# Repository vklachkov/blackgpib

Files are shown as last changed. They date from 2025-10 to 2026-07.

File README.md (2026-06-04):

# BlackGPIB

BlackGPIB is hardware that emulates GPIB disk drives for the GRiD Compass. It is based on the Raspberry Pi RP2040.

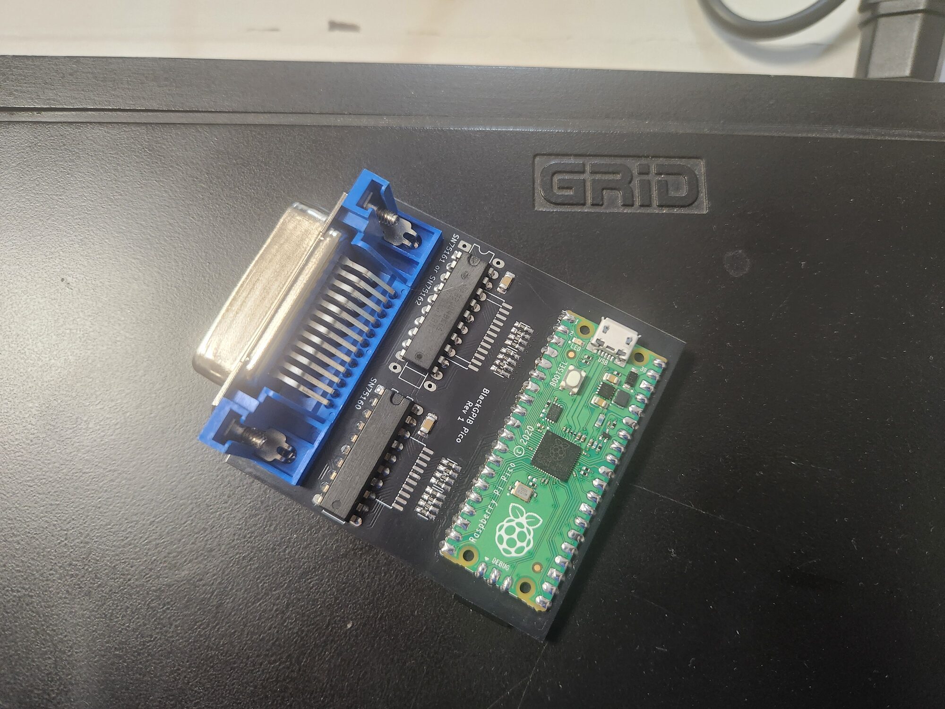
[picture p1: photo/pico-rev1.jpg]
Pico Rev 1


## Hardware

Hardware schematics and design files are located in the `hardware` folder. Production files are available in the [latest release](github.com/vklachkov/blackgpib/releases) on GitHub.

We recommend using the latest `pico` version. The list of components and known issues is described in the `README.md` file located in the `hardware/pico` directory.

## Firmware

The firmware source code is located in the `pico` folder.

The latest stable prebuilt firmware in UF2 format is available in the [latest release](https://github.com/vklachkov/blackgpib/releases) on GitHub.

### Flashing prebuilt firmware

To flash the firmware, hold the **BOOTSEL** button while connecting the Raspberry Pi Pico to your computer. The Pico will appear as a removable drive.

Copy the `blackgpib.uf2` file to this drive. The Pico will reboot automatically after the file is copied.

### Building firmware from source

To build the firmware yourself, install the Pico SDK first. Follow the instructions on the official Raspberry Pi website:

https://www.raspberrypi.com/documentation/microcontrollers/c_sdk.html

Then follow these steps.

1. Clone the repository:

```bash
git clone --depth 1 --recursive https://github.com/vklachkov/blackgpib
```

2. Go to the sources directory:

```bash
cd blackgpib/pico
```

3. Configure the project for your board:

```bash
cmake -S . -B build -DPICO_BOARD=pico
```

4. Build:

```bash
cmake --build build -j
```

5. Flash the firmware:

   Hold the **BOOTSEL** button while connecting the Raspberry Pi Pico to your computer. Then copy the `blackgpib.uf2` file from the `build` folder to the mounted Pico drive.

## How to use it?

After assembling and flashing the device, find a microSD card and format it as FAT32 or exFAT. Copy the disk images to this card. Insert the microSD card into BlackGPIB. Connect BlackGPIB to power, the LED should turn on after about one and a half seconds. After that, you can turn on the GRiD Compass. Enjoy!

### Which file formats are supported?

Currently, only .IMG files are supported. IMD and .CHD are not supported.

If you want to use IMD files from gridrepository.org, please use the [imd2raw](https://github.com/RetroFloppy/imd2raw) converter until BlackGPIB support is not available.

### How is the address selected?

For images that do not have a GPIB address specified in their filename, the address is selected automatically.

Floppy disk images use addresses 5, 6, and 13. Other images use the remaining default addresses (4, 5, 6, 12, 13).

If addresses conflict, or if there are no addresses left, an entry about this will be written to log.txt.

### How do I bind an image to a specific GPIB address?

Rename the image to FXX or HXX, where XX is the GPIB address. For example, FLOPPY4_TEST.IMG or HD12.IMG.

### How do I change the image geometry?

You can’t, it is selected automatically. Geometry configuration is not supported.

### Troubleshooting

**The LED is always off**

Check that you assembled the emulator correctly, powered it, and flashed the correct firmware.

**The device is steadily blinking the LED on the board**

This means that the device does not see the SD card, or the filesystem on it is not FAT.

Remove the SD card, format it again, and insert it into the device. If you did not disconnect power from BlackGPIB, then, if successful, the device will blink the LED several times, and then the LED should stay steadily on. This means that the device is ready to use.

**The device is blinking SOS**

This means that the device has gone into a boot loop. Normally, this should not happen.

Connect the device to your computer, open a serial port monitor, and check what went wrong before the boot loop. You can email me or open an issue, and I will try to help.

## License

This project is released under the [MIT License](LICENSE).

You are free to use, modify, and share it. I will be happy if BlackGPIB helps you bring your GRiD Compass back to life and use it again.

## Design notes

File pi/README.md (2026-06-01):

# BlackGPIB Legacy

This is a project to emulate GPIB peripherals for the [GRiD Compass](https://en.wikipedia.org/wiki/Grid_Compass) computer using Raspberry Pi.

## Features

BlackGPIB can emulate a hard drive and a floppy drive. It also has a printer and plotter proxy. Current version is based on Raspberry Pi 3 or newer. Support for Raspberry Pi 2 is not implemented due to the need to adapt the code for armv6.

For more information about device emulation, see the [Details About Emulation](#details-about-emulation) section.

## Photos

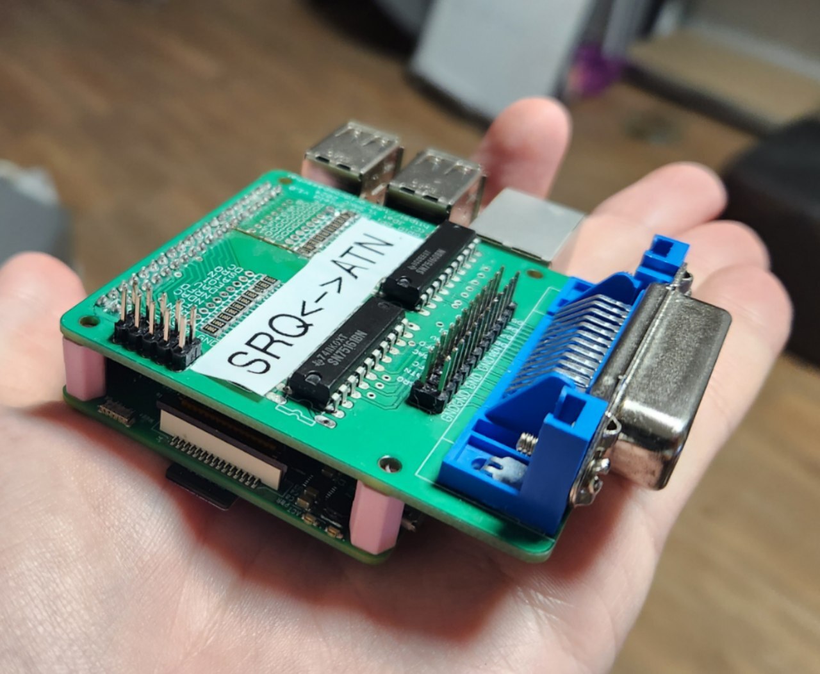
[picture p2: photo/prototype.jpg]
Photo of first prototype

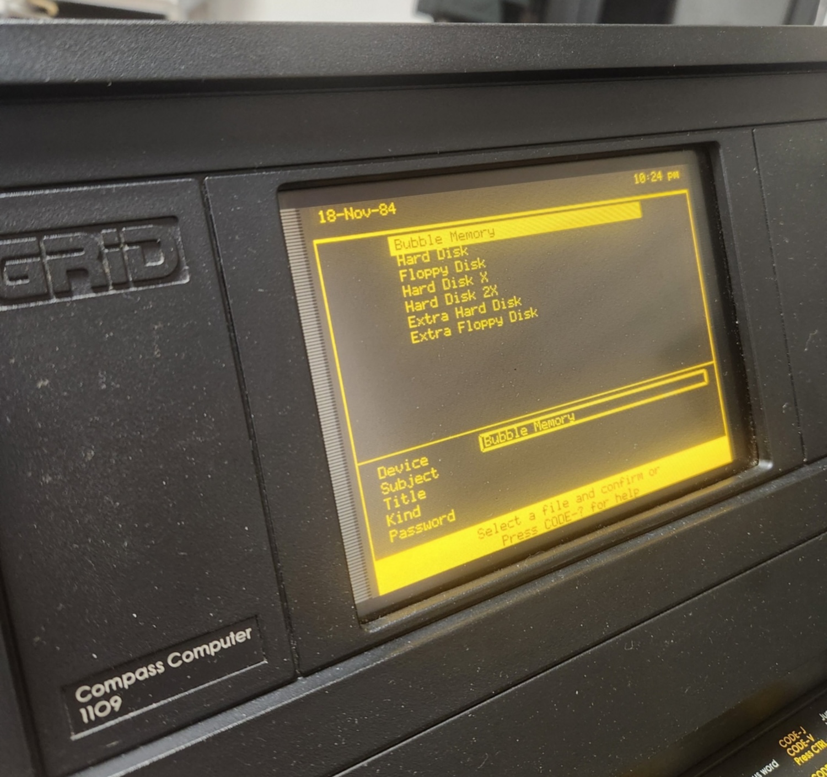
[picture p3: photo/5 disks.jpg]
5 disks


## How to Assemble

There is no illustrated guide, and there won't be one until a new version of the board is developed. If you are interested in assembling a prototype, you can find the board project files and their description in the [`hardware/pi-hat`](/hardware/pi-hat) folder.

## Prepare Raspberry Pi

For stable work please setup a real-time (RT) kernel on your Raspberry Pi. Otherwise, sometimes the emulator may sometimes hang and the Compass will show timeout errors.

To build and install kernel please read official instruction from Raspberry Pi: https://www.raspberrypi.com/documentation/computers/linux_kernel.html.

Before building, check the "Configure the kernel" section and enable Real Time mode. You'll need to select "Fully Preemptible Kernel (Real-Time)" in menu "General Setup" -> "Preemption Model".

The kernel from the official repository isn't working.

## How to Build Software

To build the project, you need to install the latest [Rust](https://rust-lang.org/) compiler.

Clone this repository:

```
git clone --depth 1 https://github.com/vklachkov/blackgpib.git
```

Go to `Pi` directory:

```
cd pi
```

Then, just run:

```
make build
```

After this, the binary file will be created at `target/aarch64-unknown-linux-gnu/release/blackgpib`.

Copy this file to your Raspberry Pi and try it.

## How to Configure the emulator

For a detailed description of how to use BlackGPIB, run the program with the `-h` option.

## Disk Images for Emulator

The disks with the operating system and instructions for making your own disks are in the [`disks/`](/disks/) folder.

## Details About Emulation

### Block Devices

The GRiD Compass does not see any difference between a floppy drive and a hard disk. For the computer, both are just "block devices".

BlackGPIB can emulate disks for reading and writing at all standard addresses: 4, 5, 6, 12, and 13. Disks at non-standard addresses are not supported (for now).

The emulator doesn't support all known commands, only the most essential ones: Initialize, Status, Read, Write, and Format.

### Printer and Plotter

BlackGPIB can emulate a printer and a plotter. It connects to the right addresses and sends everything from the laptop as UDP broadcast to `49275` for printer and `49276` for plotter.

A proxy for CUPS or any other system is not part of this project and will not be added to this repository.

You can make your own proxy if you like:

🖨️ For the printer proxy, we recommend using the Epson MX-82 driver and making your own converter for ESC/P commands.

🖊️ For the plotter proxy, you need to make a converter from HP-GL (not HP-GL/2) to something else. The commands from the laptop may be different from the standard, so please use documentation for supported plotters.

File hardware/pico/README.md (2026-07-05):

# BlackGPIB Pico



## Components

| Part | Value | Package | Quantity | Comment |
|---|---|---|---|---|
| GPIB Connector Female | - | 90 Degree | 1 | |
| SN75160 | - | SMD or DIP | 1 | |
| SN75161 / SN75162 | - | SMD or DIP | 1 | |
| Resistor Pack (4x0603) | 3.3kΩ | 1206 (4x0603) | 2 | Front side of the board |
| Resistor Pack (4x0603) | 6.8kΩ | 1206 (4x0603) | 2 | Back side of the board |
| Ceramic Capacitor | 0.1µF | 1206 | 3 | Any for 5V, I used random 10V capacitor |
| Tantalum Capacitor | 100µF | Case C (6032) | 1 | Any for 3.3V, I used random 10V capacitor |
| MicroSD Card Slot | - | SMD | 1 | [LSCS](https://www.lcsc.com/product-detail/C114218.html) |
| Pi Pico 2040 | - | SMD | 1 | |

## Known problems

### Rev 1

Because the Raspberry Pi Pico is positioned far from the edge of the board, not all micro-USB cables will fit.

When inserting the cable, hold it gently to prevent the SD card from popping out of the slot.

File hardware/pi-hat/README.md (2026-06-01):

# First board by @JDat for Raspberry Pi 2+

This is the first revision of the board, designed by @JDat (also known as @YL3AKC):

Photo of prototype

In the photo, it's the old version with SRQ and ATN swapped.

## Components

| Part | Value | Package | Quantity |
|---|---|---|---|
| GPIB Connector Female | - | 90 Degree  | 1 |
| SN75160 | - | SMD or DIP | 1 |
| SN75161/SN75162 | - | SMD or DIP | 1 |
| Resistor | 3kΩ | 0805 | 20 |
| Capacitor | 0.1uF | 0805 | 2 |
| Pin Header | 20x2 Straight Female | - | 1 |

P.S. Instead of small SMD components, you can also use through-hole components, as Kirill @BOOtak Leyfer did.

https://t.me/bootaks_old_devices/286

## Errata

### Not enough space for the through-hole resistors.

As can be seen in Kirill's photo, the resistors are placed too close together, requiring them to be stacked on top of each other.

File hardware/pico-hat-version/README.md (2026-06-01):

An experimental version of the Pico-based emulator, but with the GPIB interface implemented on the [`hardware/pi-hat`](hardware/pi-hat) board. Unsupported by modern firmwares.

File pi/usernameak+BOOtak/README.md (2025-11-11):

# Unfinished Version by @BOOtak

This folder contains the unfinished source code for the very first attempt to make an emulator:

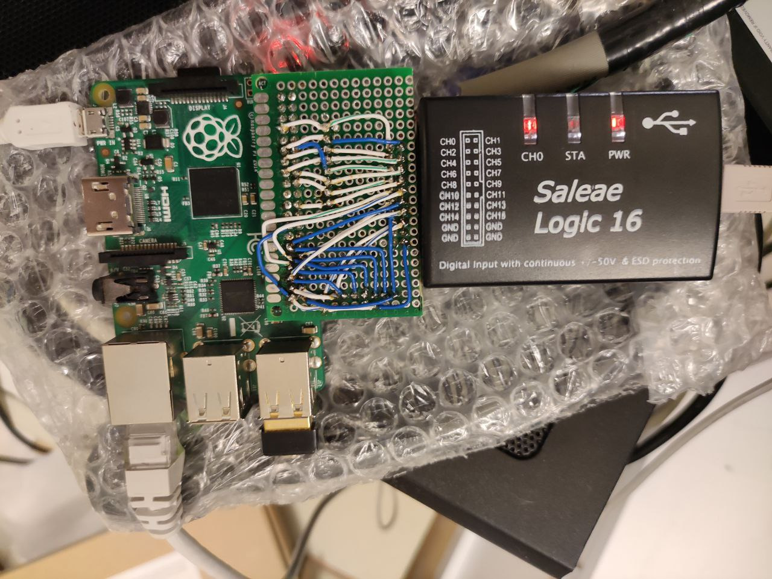
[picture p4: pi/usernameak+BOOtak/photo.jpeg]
First prototype photo


The source code by Kirill Leyfer is based on the work of @usernameak for GRiD Compass emulation in MAME64:

[src/devices/bus/ieee488/grid2102.cpp](https://github.com/mamedev/mame/blob/c27c33cd833ab732b275ef04da03d1d97c42297b/src/devices/bus/ieee488/grid2102.cpp)  
[src/devices/bus/ieee488/grid2102.h](https://github.com/mamedev/mame/blob/c27c33cd833ab732b275ef04da03d1d97c42297b/src/devices/bus/ieee488/grid2102.h)

Kirill tried to debug this thing during a few YouTube streams:

https://www.youtube.com/watch?v=bkrvHpA3saQ  
https://www.youtube.com/watch?v=xkkKw8rbxL4  
https://www.youtube.com/watch?v=xiMl4WMsztg

Dumps and dump analyzers are saved "as is" in their folders for historical reasons.

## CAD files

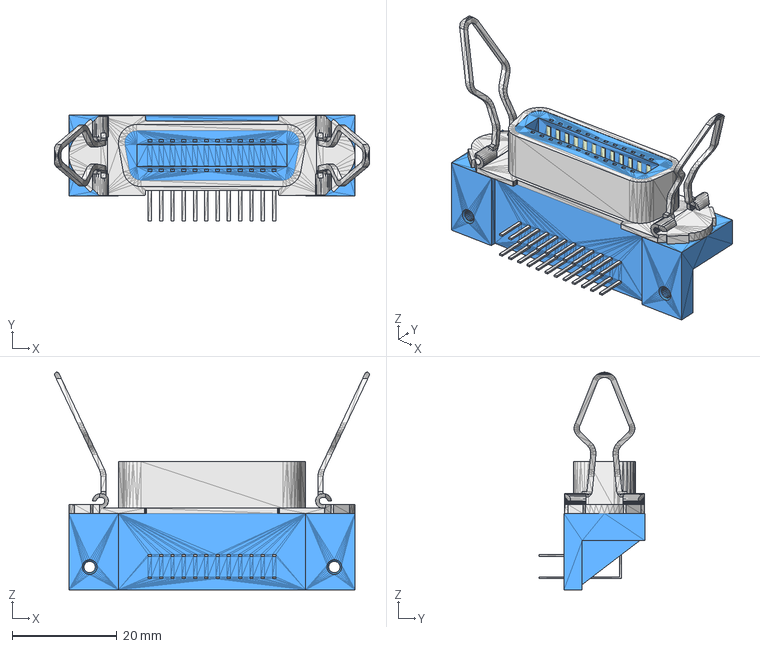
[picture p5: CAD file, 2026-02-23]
hardware/pico/BlackGPIB Pico.models/Centronics 24.step
60.2 x 20.3 x 41.6 mm

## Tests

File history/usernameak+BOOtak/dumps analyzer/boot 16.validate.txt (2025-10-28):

DIO[0] change while low DAV at 0.751559000s!
DIO[4] change while low DAV at 0.755732125s!
ATN change while low DAV at 4.882046750s!
ATN change while low DAV at 4.893509750s!
6.923426313: dt = 63 < 100 at NRFD!
ATN change while low DAV at 6.952843687s!
ATN change while low DAV at 7.054632563s!
ATN change while low DAV at 7.173064875s!
ATN change while low DAV at 7.275151125s!
7.364383875: dt = 63 < 100 at NRFD!
ATN change while low DAV at 7.412919813s!
7.416207812: dt = 62 < 100 at NRFD!
7.419468937: dt = 62 < 100 at DIO3, DIO7!
ATN change while low DAV at 7.425247125s!
7.523888688: dt = 63 < 100 at NRFD!
ATN change while low DAV at 7.554071750s!
ATN change while low DAV at 7.581283062s!
7.587062875: dt = 62 < 100 at DIO3, DIO7!
ATN change while low DAV at 7.593506563s!
ATN change while low DAV at 7.856298687s!
ATN change while low DAV at 7.979138563s!
8.267142313: dt = 63 < 100 at NRFD!
ATN change while low DAV at 8.297223375s!
ATN change while low DAV at 8.421231875s!
ATN change while low DAV at 8.697375500s!
ATN change while low DAV at 8.861291062s!
ATN change while low DAV at 9.215970125s!
ATN change while low DAV at 9.320451875s!
ATN change while low DAV at 9.438666625s!
ATN change while low DAV at 9.556983875s!
9.626585063: dt = 63 < 100 at NRFD!
ATN change while low DAV at 9.658962688s!
EOI change while low DAV at 9.777333188s!
ATN change while low DAV at 9.879663125s!
ATN change while low DAV at 9.997970813s!
10.067557562: dt = 62 < 100 at NRFD!
10.092066625: dt = 63 < 100 at DIO7!
ATN change while low DAV at 10.100008750s!
10.185977625: dt = 63 < 100 at NRFD!
ATN change while low DAV at 10.218376625s!
ATN change while low DAV at 10.320432812s!
10.430982500: dt = 62 < 100 at DIO7!
ATN change while low DAV at 10.439070437s!
ATN change while low DAV at 10.557410875s!
ATN change while low DAV at 10.659492438s!
10.745413687: dt = 62 < 100 at NRFD!
ATN change while low DAV at 10.777796688s!
ATN change while low DAV at 10.879883438s!
10.966132250: dt = 63 < 100 at NRFD!
10.990462313: dt = 63 < 100 at DIO3, DIO7!
ATN change while low DAV at 10.998545438s!
ATN change while low DAV at 11.100469625s!
11.186409438: dt = 63 < 100 at NRFD!
ATN change while low DAV at 11.218903625s!
11.312927625: dt = 62 < 100 at DIO3, DIO7!
ATN change while low DAV at 11.320877000s!
11.406895375: dt = 63 < 100 at NRFD!
11.431330625: dt = 63 < 100 at DIO3, DIO7!
ATN change while low DAV at 11.437824750s!
ATN change while low DAV at 11.718866063s!
ATN change while low DAV at 11.839821375s!
ATN change while low DAV at 11.957723250s!
12.027332188: dt = 63 < 100 at NRFD!
ATN change while low DAV at 12.060145312s!
ATN change while low DAV at 12.178153375s!
ATN change while low DAV at 12.280800875s!
12.390607562: dt = 62 < 100 at DIO3, DIO7!
ATN change while low DAV at 12.399154625s!
ATN change while low DAV at 12.500775250s!
ATN change while low DAV at 12.619525000s!
EOI change while low DAV at 12.721193188s!
12.831716375: dt = 63 < 100 at DIO3, DIO7!
ATN change while low DAV at 12.840241688s!
12.950012375: dt = 62 < 100 at DIO3, DIO7!
ATN change while low DAV at 12.958168125s!
ATN change while low DAV at 13.060596000s!
ATN change while low DAV at 13.178599812s!
13.272687188: dt = 63 < 100 at DIO7!
ATN change while low DAV at 13.281023313s!
ATN change while low DAV at 13.399173875s!
ATN change while low DAV at 13.501565188s!
13.587195188: dt = 63 < 100 at NRFD!
ATN change while low DAV at 13.619646750s!
ATN change while low DAV at 13.722044875s!
ATN change while low DAV at 13.840038875s!
13.950481687: dt = 62 < 100 at DIO3, DIO7!
ATN change while low DAV at 13.959009000s!
ATN change while low DAV at 14.060508125s!
ATN change while low DAV at 14.179304062s!
14.248473437: dt = 62 < 100 at NRFD!
ATN change while low DAV at 14.280853063s!
ATN change while low DAV at 14.399704125s!
ATN change while low DAV at 14.501464063s!
14.587446062: dt = 62 < 100 at NRFD!
ATN change while low DAV at 14.620307813s!
14.689495562: dt = 62 < 100 at NRFD!
ATN change while low DAV at 14.721956750s!
14.832354750: dt = 62 < 100 at DIO3, DIO7!
ATN change while low DAV at 14.840681250s!
ATN change while low DAV at 14.958780250s!
15.028668938: dt = 63 < 100 at NRFD!
ATN change while low DAV at 15.061552250s!
ATN change while low DAV at 15.179406063s!
15.248920000: dt = 62 < 100 at NRFD!
EOI change while low DAV at 15.281763375s!
15.367404750: dt = 62 < 100 at NRFD!
15.391849188: dt = 63 < 100 at DIO7!
ATN change while low DAV at 15.399795750s!
ATN change while low DAV at 15.502204000s!
15.588100750: dt = 62 < 100 at NRFD!
15.612416000: dt = 63 < 100 at DIO3, DIO7!
ATN change while low DAV at 15.620373562s!
ATN change while low DAV at 15.722767188s!
ATN change while low DAV at 15.840819563s!
ATN change while low DAV at 15.959415875s!
16.028723250: dt = 63 < 100 at NRFD!
ATN change while low DAV at 16.061079813s!
16.147372562: dt = 62 < 100 at NRFD!
ATN change while low DAV at 16.180036687s!
16.273508312: dt = 62 < 100 at DIO3, DIO7!
ATN change while low DAV at 16.281669250s!
16.367640188: dt = 63 < 100 at NRFD!
ATN change while low DAV at 16.400488500s!
ATN change while low DAV at 16.502122875s!
16.612584438: dt = 63 < 100 at DIO7!
ATN change while low DAV at 16.620913125s!
ATN change while low DAV at 16.722662062s!
16.832921250: dt = 63 < 100 at DIO7!
ATN change while low DAV at 16.841450750s!
16.927121312: dt = 62 < 100 at NRFD!
ATN change while low DAV at 16.959647875s!
17.053648813: dt = 63 < 100 at DIO3, DIO7!
ATN change while low DAV at 17.061964938s!
ATN change while low DAV at 17.179993875s!
17.274175187: dt = 62 < 100 at DIO3, DIO7!
ATN change while low DAV at 17.282502875s!
ATN change while low DAV at 17.400589062s!
17.470154750: dt = 63 < 100 at NRFD!
ATN change while low DAV at 17.503037500s!
17.588604062: dt = 62 < 100 at NRFD!
ATN change while low DAV at 17.621017812s!
17.690665312: dt = 62 < 100 at NRFD!
ATN change while low DAV at 17.723444625s!
17.833571250: dt = 63 < 100 at DIO3, DIO7!
ATN change while low DAV at 17.841524625s!
ATN change while low DAV at 17.960336687s!
ATN change while low DAV at 18.061954375s!
ATN change while low DAV at 18.180669812s!
ATN change while low DAV at 18.282392937s!
ATN change while low DAV at 18.401262813s!
18.494818750: dt = 62 < 100 at DIO3!
ATN change while low DAV at 18.502962687s!
ATN change while low DAV at 18.621765750s!
18.715439688: dt = 63 < 100 at DIO3!
ATN change while low DAV at 18.723394813s!
ATN change while low DAV at 18.842183500s!
EOI change while low DAV at 18.960317062s!
ATN change while low DAV at 19.062719250s!
ATN change while low DAV at 19.180805187s!
ATN change while low DAV at 19.283139375s!
19.368824750: dt = 63 < 100 at NRFD!
19.393268187: dt = 62 < 100 at DIO7!
ATN change while low DAV at 19.401223125s!
ATN change while low DAV at 19.503711125s!
ATN change while low DAV at 19.621823062s!
19.691372750: dt = 63 < 100 at NRFD!
ATN change while low DAV at 19.724197063s!
19.809794625: dt = 63 < 100 at NRFD!
19.834221250: dt = 63 < 100 at DIO3, DIO7!
ATN change while low DAV at 19.842172625s!
ATN change while low DAV at 19.960935438s!
20.030181563: dt = 63 < 100 at NRFD!
ATN change while low DAV at 20.062637563s!
20.148630063: dt = 63 < 100 at NRFD!
ATN change while low DAV at 20.181483000s!
ATN change while low DAV at 20.283140688s!
ATN change while low DAV at 20.401903125s!
ATN change while low DAV at 20.503575812s!
ATN change while low DAV at 20.622470813s!
20.716003375: dt = 63 < 100 at DIO7!
ATN change while low DAV at 20.724157500s!
ATN change while low DAV at 20.842945750s!
20.928574687: dt = 62 < 100 at NRFD!
20.953008312: dt = 62 < 100 at DIO3, DIO7!
ATN change while low DAV at 20.960951250s!
21.055047750: dt = 62 < 100 at DIO3, DIO7!
ATN change while low DAV at 21.063374062s!
ATN change while low DAV at 21.181524938s!
21.251097625: dt = 62 < 100 at NRFD!
21.275395062: dt = 62 < 100 at DIO3, DIO7!
ATN change while low DAV at 21.283927125s!
ATN change while low DAV at 21.402023875s!
ATN change while low DAV at 21.504379437s!
21.590074000: dt = 62 < 100 at NRFD!
21.614511625: dt = 63 < 100 at DIO7!
ATN change while low DAV at 21.622463187s!
ATN change while low DAV at 21.724922375s!
ATN change while low DAV at 21.843019625s!
ATN change while low DAV at 21.961722500s!
ATN change while low DAV at 22.063343375s!
ATN change while low DAV at 22.182124188s!
22.251400875: dt = 62 < 100 at NRFD!
ATN change while low DAV at 22.283859625s!
22.394199562: dt = 62 < 100 at DIO3, DIO7!
ATN change while low DAV at 22.402729063s!
22.471940562: dt = 62 < 100 at NRFD!
22.496260187: dt = 62 < 100 at DIO3, DIO7!
ATN change while low DAV at 22.504420500s!
ATN change while low DAV at 22.623134938s!
22.692436625: dt = 63 < 100 at NRFD!
ATN change while low DAV at 22.724808625s!
ATN change while low DAV at 22.843690625s!
22.929353938: dt = 63 < 100 at NRFD!
22.953676563: dt = 63 < 100 at DIO3, DIO7!
ATN change while low DAV at 22.961824875s!
ATN change while low DAV at 23.064234438s!
ATN change while low DAV at 23.182252563s!
ATN change while low DAV at 23.284648750s!
ATN change while low DAV at 23.402813438s!
23.496696312: dt = 62 < 100 at DIO7!
ATN change while low DAV at 23.505216000s!
23.590864312: dt = 62 < 100 at NRFD!
ATN change while low DAV at 23.623349063s!
EOI change while low DAV at 23.725628687s!
ATN change while low DAV at 23.843702938s!
ATN change while low DAV at 23.962441750s!
24.056040875: dt = 62 < 100 at DIO7!
ATN change while low DAV at 24.064188563s!
ATN change while low DAV at 24.182983562s!
24.276631500: dt = 62 < 100 at DIO3, DIO7!
ATN change while low DAV at 24.284583438s!
24.395118938: dt = 63 < 100 at DIO7!
ATN change while low DAV at 24.403449812s!
ATN change while low DAV at 24.505110062s!
24.591217938: dt = 63 < 100 at NRFD!
24.615530375: dt = 63 < 100 at DIO3, DIO7!
ATN change while low DAV at 24.624064250s!
24.693217750: dt = 63 < 100 at NRFD!
ATN change while low DAV at 24.725657500s!
25.150682625: dt = 63 < 100 at NRFD!
25.174973250: dt = 62 < 100 at DIO3, DIO7!
ATN change while low DAV at 25.183503313s!
ATN change while low DAV at 25.285151375s!
25.395562063: dt = 63 < 100 at DIO3, DIO7!
ATN change while low DAV at 25.403899187s!
25.497605250: dt = 63 < 100 at DIO3, DIO7!
ATN change while low DAV at 25.505558375s!
ATN change while low DAV at 25.624441375s!
25.693709250: dt = 62 < 100 at NRFD!
25.718014875: dt = 62 < 100 at DIO3, DIO7!
ATN change while low DAV at 25.726156000s!
25.812132875: dt = 63 < 100 at NRFD!
ATN change while low DAV at 29.154237625s!
EOI change while low DAV at 29.165774813s!
ATN change while low DAV at 34.531101000s!
34.533814875: dt = 63 < 100 at NRFD!
ATN change while low DAV at 34.542306188s!
36.449531187: dt = 62 < 100 at NRFD!
36.473761813: dt = 63 < 100 at DIO7!
ATN change while low DAV at 36.479197187s!
ATN change while low DAV at 36.505485562s!
ATN change while low DAV at 36.523427625s!
ATN change while low DAV at 36.793390313s!
36.870142562: dt = 62 < 100 at NRFD!
36.894298375: dt = 63 < 100 at DIO3, DIO7!
ATN change while low DAV at 36.921364250s!
ATN change while low DAV at 37.232024938s!
37.311180125: dt = 62 < 100 at NRFD!
ATN change while low DAV at 37.533885062s!
ATN change while low DAV at 38.011708812s!
ATN change while low DAV at 38.167309125s!
38.331963812: dt = 62 < 100 at NRFD!
ATN change while low DAV at 38.365623000s!
38.650457250: dt = 62 < 100 at NRFD!
38.674692063: dt = 63 < 100 at DIO7!
ATN change while low DAV at 38.687504438s!
39.074907813: dt = 63 < 100 at DIO3, DIO7!
ATN change while low DAV at 39.104295437s!
ATN change while low DAV at 39.115510000s!
39.474856375: dt = 62 < 100 at DIO3!
ATN change while low DAV at 39.480449562s!
ATN change while low DAV at 39.506632500s!
39.510420063: dt = 63 < 100 at NRFD!
ATN change while low DAV at 39.524785750s!
ATN change while low DAV at 39.794652437s!
ATN change while low DAV at 39.922388375s!
40.193963813: dt = 63 < 100 at NRFD!
ATN change while low DAV at 40.233234563s!
ATN change while low DAV at 40.365116250s!
ATN change while low DAV at 40.650308625s!
40.814971500: dt = 63 < 100 at NRFD!
40.839114313: dt = 63 < 100 at DIO3, DIO7!
ATN change while low DAV at 40.886993313s!
40.892842875: dt = 63 < 100 at DIO3, DIO7!
ATN change while low DAV at 40.898357500s!
41.051528187: dt = 62 < 100 at NRFD!
41.075668000: dt = 62 < 100 at DIO7!
ATN change while low DAV at 41.081258187s!
ATN change while low DAV at 41.107455750s!
ATN change while low DAV at 41.125977125s!
41.353704312: dt = 62 < 100 at NRFD!
ATN change while low DAV at 41.397312812s!
41.472334000: dt = 63 < 100 at NRFD!
41.496484625: dt = 62 < 100 at DIO3, DIO7!
ATN change while low DAV at 41.526002187s!
41.818876563: dt = 63 < 100 at DIO3, DIO7!
ATN change while low DAV at 41.835762750s!
41.913166875: dt = 62 < 100 at NRFD!
ATN change while low DAV at 41.980102250s!
ATN change while low DAV at 42.210235000s!
ATN change while low DAV at 42.425914938s!
42.510068125: dt = 63 < 100 at DIO4!
ATN change while low DAV at 42.526891750s!
ATN change while low DAV at 42.628848813s!
42.713636562: dt = 62 < 100 at NRFD!
ATN change while low DAV at 42.747353125s!
42.815667062: dt = 62 < 100 at NRFD!
ATN change while low DAV at 42.901431000s!
ATN change while low DAV at 43.168007188s!
43.276733937: dt = 62 < 100 at DIO7!
ATN change while low DAV at 43.286299062s!
ATN change while low DAV at 43.388489937s!
ATN change while low DAV at 43.524416375s!
ATN change while low DAV at 43.608836750s!
43.693807062: dt = 62 < 100 at NRFD!
ATN change while low DAV at 43.727539625s!
43.795804938: dt = 63 < 100 at NRFD!
43.819960750: dt = 62 < 100 at DIO7!
ATN change while low DAV at 43.829540313s!
43.938288063: dt = 63 < 100 at DIO7!
ATN change while low DAV at 43.965533687s!
44.240556938: dt = 63 < 100 at DIO3!
ATN change while low DAV at 44.249974500s!
ATN change while low DAV at 44.368659375s!
44.453083750: dt = 63 < 100 at NRFD!
ATN change while low DAV at 44.486792500s!
ATN change while low DAV at 44.606635625s!
ATN change while low DAV at 44.707378062s!
44.799918375: dt = 63 < 100 at DIO3, DIO7!
ATN change while low DAV at 44.809325375s!
ATN change while low DAV at 44.927999625s!
45.020401750: dt = 63 < 100 at DIO7!
ATN change while low DAV at 45.047636750s!
ATN change while low DAV at 45.148435562s!
ATN change while low DAV at 45.250396688s!
ATN change while low DAV at 45.368834937s!
45.453837250: dt = 63 < 100 at NRFD!
ATN change while low DAV at 45.505225125s!
45.579926750: dt = 63 < 100 at DIO3, DIO7!
ATN change while low DAV at 45.589514937s!
45.674275438: dt = 63 < 100 at NRFD!
ATN change while low DAV at 45.707988563s!
ATN change while low DAV at 45.809971500s!
ATN change while low DAV at 45.946087437s!
46.196893063: dt = 63 < 100 at NRFD!
46.221040875: dt = 62 < 100 at DIO3, DIO7!
ATN change while low DAV at 46.230621625s!
ATN change while low DAV at 46.349099313s!
ATN change while low DAV at 46.451085562s!
ATN change while low DAV at 46.587191750s!
46.654227187: dt = 62 < 100 at NRFD!
ATN change while low DAV at 46.688116313s!
46.780406062: dt = 62 < 100 at DIO3, DIO7!
ATN change while low DAV at 46.789993813s!
46.874758937: dt = 62 < 100 at NRFD!
ATN change while low DAV at 46.908469500s!
ATN change while low DAV at 47.028129250s!
47.095232688: dt = 63 < 100 at NRFD!
ATN change while low DAV at 47.128891625s!
ATN change while low DAV at 47.231189687s!
ATN change while low DAV at 47.349450563s!
ATN change while low DAV at 47.469176125s!
ATN change while low DAV at 47.569910312s!
47.654829625: dt = 63 < 100 at NRFD!
47.679104813: dt = 63 < 100 at DIO3, DIO7!
ATN change while low DAV at 47.688513812s!
47.757000875: dt = 62 < 100 at NRFD!
47.781160875: dt = 63 < 100 at DIO3, DIO7!
ATN change while low DAV at 47.790747250s!
47.899492563: dt = 63 < 100 at DIO3, DIO7!
ATN change while low DAV at 47.926717000s!
ATN change while low DAV at 48.211151375s!
ATN change while low DAV at 48.329592625s!
ATN change while low DAV at 48.431968688s!
ATN change while low DAV at 48.567899250s!
ATN change while low DAV at 48.652251812s!
ATN change while low DAV at 48.770646937s!
48.855257438: dt = 63 < 100 at NRFD!
48.879500625: dt = 63 < 100 at DIO3, DIO7!
ATN change while low DAV at 48.888917187s!
48.957362688: dt = 63 < 100 at NRFD!
48.981603687: dt = 62 < 100 at DIO7!
ATN change while low DAV at 49.008776938s!
49.075836750: dt = 62 < 100 at NRFD!
ATN change while low DAV at 49.109571500s!
ATN change while low DAV at 49.211641937s!
49.296396063: dt = 63 < 100 at NRFD!
49.320644063: dt = 63 < 100 at DIO3, DIO7!
ATN change while low DAV at 49.330053062s!
ATN change while low DAV at 49.449733750s!
ATN change while low DAV at 49.550849500s!
49.643105250: dt = 63 < 100 at DIO3, DIO7!
ATN change while low DAV at 49.652680813s!
49.761612312: dt = 62 < 100 at DIO7!
ATN change while low DAV at 49.771198250s!
ATN change while low DAV at 49.907287188s!
49.957934625: dt = 62 < 100 at NRFD!
ATN change while low DAV at 49.991626563s!
50.076380687: dt = 62 < 100 at NRFD!
50.100632875: dt = 62 < 100 at DIO3, DIO7!
ATN change while low DAV at 50.110203250s!
50.178460937: dt = 62 < 100 at NRFD!
ATN change while low DAV at 50.212191313s!
50.321135187: dt = 62 < 100 at DIO3, DIO7!
ATN change while low DAV at 50.350640000s!
50.599165812: dt = 62 < 100 at NRFD!
ATN change while low DAV at 50.632817938s!
ATN change while low DAV at 50.751282438s!
50.819804500: dt = 63 < 100 at NRFD!
ATN change while low DAV at 50.853554875s!
50.938084375: dt = 62 < 100 at NRFD!
ATN change while low DAV at 50.998678625s!
ATN change while low DAV at 51.090235375s!
ATN change while low DAV at 51.192205063s!
ATN change while low DAV at 51.310664500s!
51.379169563: dt = 63 < 100 at NRFD!
ATN change while low DAV at 51.433402500s!
51.497518250: dt = 63 < 100 at NRFD!
ATN change while low DAV at 51.531228000s!
ATN change while low DAV at 51.633290438s!
51.718018937: dt = 62 < 100 at NRFD!
ATN change while low DAV at 51.751678125s!
ATN change while low DAV at 51.872420125s!
ATN change while low DAV at 51.972603937s!
52.057154875: dt = 62 < 100 at NRFD!
ATN change while low DAV at 52.090881250s!
ATN change while low DAV at 52.192922688s!
ATN change while low DAV at 52.337390500s!
52.603946750: dt = 63 < 100 at DIO3, DIO7!
ATN change while low DAV at 52.619071312s!
52.722300000: dt = 63 < 100 at DIO3!
ATN change while low DAV at 52.730586688s!
ATN change while low DAV at 52.833972563s!
52.942904687: dt = 62 < 100 at DIO7!
ATN change while low DAV at 52.952354437s!
ATN change while low DAV at 53.054474687s!
53.139335563: dt = 63 < 100 at NRFD!
ATN change while low DAV at 53.180591312s!
53.383814875: dt = 63 < 100 at DIO7!
ATN change while low DAV at 53.392353562s!
ATN change while low DAV at 53.511913875s!
ATN change while low DAV at 53.613931313s!
53.696698000: dt = 63 < 100 at NDAC, NRFD!
ATN change while low DAV at 53.732585125s!
53.824852812: dt = 62 < 100 at DIO3!
ATN change while low DAV at 53.863800375s!
ATN change while low DAV at 53.952952625s!
ATN change while low DAV at 54.054972437s!
ATN change while low DAV at 54.173421312s!
54.282540563: dt = 63 < 100 at DIO3!
ATN change while low DAV at 54.310330125s!
54.560385563: dt = 63 < 100 at NRFD!
ATN change while low DAV at 54.594163313s!
ATN change while low DAV at 54.712620937s!
ATN change while low DAV at 54.814634562s!
ATN change while low DAV at 54.951536438s!
ATN change while low DAV at 55.235413562s!
55.318206688: dt = 63 < 100 at NDAC!
55.344421250: dt = 63 < 100 at DIO3, DIO7!
ATN change while low DAV at 55.353866188s!
55.422159500: dt = 63 < 100 at NRFD!
55.446411688: dt = 63 < 100 at DIO3, DIO7!
ATN change while low DAV at 55.455867625s!
55.564950313: dt = 63 < 100 at DIO3, DIO7!
ATN change while low DAV at 55.601848500s!
ATN change while low DAV at 55.892781062s!
ATN change while low DAV at 55.994822312s!
ATN change while low DAV at 56.113258313s!
ATN change while low DAV at 56.236609812s!
56.300096438: dt = 63 < 100 at NRFD!
ATN change while low DAV at 56.333876375s!
56.402158875: dt = 63 < 100 at NRFD!
ATN change while low DAV at 56.435924625s!
ATN change while low DAV at 56.554366250s!
ATN change while low DAV at 56.735656437s!
ATN change while low DAV at 56.747019937s!
ATN change while low DAV at 57.089386125s!
ATN change while low DAV at 57.115614625s!
57.119419750: dt = 63 < 100 at NRFD!
ATN change while low DAV at 57.135023875s!
ATN change while low DAV at 57.401345562s!
57.480408062: dt = 62 < 100 at NRFD!
ATN change while low DAV at 57.527004375s!
ATN change while low DAV at 57.840919250s!
58.003074437: dt = 62 < 100 at NRFD!
ATN change while low DAV at 58.044556125s!
58.121497062: dt = 62 < 100 at NRFD!
58.145753062: dt = 62 < 100 at DIO7!
ATN change while low DAV at 58.787409000s!
59.187039437: dt = 62 < 100 at DIO3, DIO7!
ATN change while low DAV at 59.384489688s!
59.390535000: dt = 62 < 100 at DIO7!
ATN change while low DAV at 59.395931187s!
59.661106938: dt = 63 < 100 at NRFD!
ATN change while low DAV at 59.690883687s!
ATN change while low DAV at 59.717122000s!
59.721122125: dt = 62 < 100 at NRFD!
ATN change while low DAV at 59.736455687s!
ATN change while low DAV at 60.006912875s!
60.082010813: dt = 63 < 100 at NRFD!
ATN change while low DAV at 60.137264812s!
ATN change while low DAV at 60.445134688s!
ATN change while low DAV at 60.611292500s!
60.963977000: dt = 62 < 100 at NRFD!
ATN change while low DAV at 61.000349437s!
61.188511250: dt = 63 < 100 at DIO7!
ATN change while low DAV at 61.216470188s!
61.282795062: dt = 62 < 100 at NRFD!
ATN change while low DAV at 61.316692563s!
61.408800687: dt = 62 < 100 at DIO3, DIO7!
ATN change while low DAV at 61.418409813s!
61.503041125: dt = 62 < 100 at NRFD!
ATN change while low DAV at 61.536824625s!
61.605038125: dt = 62 < 100 at NRFD!
ATN change while low DAV at 61.703660812s!
ATN change while low DAV at 61.957621188s!
ATN change while low DAV at 62.108099313s!
ATN change while low DAV at 62.119413438s!
62.486967000: dt = 62 < 100 at DIO3, DIO7!
ATN change while low DAV at 62.492467625s!
62.518835500: dt = 62 < 100 at DIO1!
ATN change while low DAV at 62.518851125s!
ATN change while low DAV at 62.538324375s!
62.765238875: dt = 62 < 100 at NRFD!
62.789398875: dt = 62 < 100 at DIO7!
ATN change while low DAV at 62.806974563s!
62.883485125: dt = 62 < 100 at NRFD!
ATN change while low DAV at 62.938525938s!
ATN change while low DAV at 63.245497125s!
63.348870375: dt = 63 < 100 at DIO7!
ATN change while low DAV at 63.547751062s!
ATN change while low DAV at 64.045679125s!
ATN change while low DAV at 64.057176625s!
ATN change while low DAV at 64.493679000s!
ATN change while low DAV at 64.519957312s!
64.523815250: dt = 62 < 100 at NRFD!
ATN change while low DAV at 64.539385000s!
64.766247875: dt = 63 < 100 at NRFD!
ATN change while low DAV at 64.808060938s!
64.884589312: dt = 62 < 100 at NRFD!
ATN change while low DAV at 64.939737875s!
65.207178750: dt = 62 < 100 at NRFD!
65.231328937: dt = 62 < 100 at DIO3, DIO7!
ATN change while low DAV at 65.246563438s!
65.325835125: dt = 62 < 100 at NRFD!
ATN change while low DAV at 65.549042188s!
65.966884312: dt = 62 < 100 at NRFD!
ATN change while low DAV at 66.080425937s!
ATN change while low DAV at 66.091872063s!
66.465187688: dt = 63 < 100 at NRFD!
ATN change while low DAV at 66.494882875s!
ATN change while low DAV at 66.521223000s!
ATN change while low DAV at 66.540408688s!
ATN change while low DAV at 66.810853625s!
ATN change while low DAV at 66.941061750s!
67.232677563: dt = 63 < 100 at DIO7!
ATN change while low DAV at 67.249396312s!
ATN change while low DAV at 67.476319875s!
ATN change while low DAV at 67.702464437s!
67.866297625: dt = 63 < 100 at NRFD!
ATN change while low DAV at 67.918587125s!
ATN change while low DAV at 68.202088812s!
68.311003875: dt = 62 < 100 at DIO3, DIO7!
ATN change while low DAV at 68.320466063s!
68.388882688: dt = 63 < 100 at NRFD!
ATN change while low DAV at 68.422595813s!
ATN change while low DAV at 68.577522813s!
68.809514937: dt = 62 < 100 at NRFD!
ATN change while low DAV at 68.843324063s!
ATN change while low DAV at 68.961666250s!
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

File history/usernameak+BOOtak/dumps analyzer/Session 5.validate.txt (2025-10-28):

2.275761375: dt = 63 < 100 at NDAC!
2.594917500: dt = 63 < 100 at DIO3, DIO4, DIO6!
2.594926437: dt = 62 < 100 at DIO1, DIO2, DIO3, DIO4, DIO5, DIO7, DIO8, SRQ, NDAC, ATN!
2.594982500: dt = 62 < 100 at NDAC!
2.595002313: dt = 63 < 100 at SRQ!
2.595013750: dt = 63 < 100 at ATN!
2.595014875: dt = 62 < 100 at ATN!
2.823998250: dt = 63 < 100 at DIO8!
2.823998312: dt = 62 < 100 at DIO8!
2.823998375: dt = 63 < 100 at DIO8!
2.823998437: dt = 62 < 100 at DIO8!
2.823998500: dt = 63 < 100 at DIO6, DIO7, DIO8!
2.823998562: dt = 62 < 100 at DIO6, DIO7, DIO8!
2.823998625: dt = 63 < 100 at DIO5, DIO6, DIO7, DIO8!
2.823998688: dt = 63 < 100 at DIO6, DIO8!
2.823998750: dt = 62 < 100 at DIO6, DIO8!
2.823998813: dt = 63 < 100 at DIO6, DIO8!
2.823998875: dt = 62 < 100 at DIO5, DIO6, DIO7, DIO8!
2.823999062: dt = 62 < 100 at DIO8!
2.823999125: dt = 63 < 100 at DIO8!
2.823999188: dt = 63 < 100 at DIO6, DIO7!
2.823999250: dt = 62 < 100 at DIO6, DIO7!
2.823999312: dt = 62 < 100 at DIO6, DIO7!
2.823999375: dt = 63 < 100 at DIO6, DIO8!
2.823999437: dt = 62 < 100 at DIO6!
2.823999500: dt = 63 < 100 at DIO6!
2.823999563: dt = 63 < 100 at DIO6, DIO7!
2.823999812: dt = 62 < 100 at DIO7!
2.823999938: dt = 63 < 100 at DIO6!
2.824000187: dt = 62 < 100 at DIO7!
2.824000438: dt = 63 < 100 at DIO7!
2.824000500: dt = 62 < 100 at DIO7!
2.824001625: dt = 63 < 100 at DIO5!
2.824001937: dt = 62 < 100 at DIO5!
2.824002000: dt = 63 < 100 at DIO5!
2.824003438: dt = 63 < 100 at DIO4!
2.824004562: dt = 62 < 100 at DIO3!
2.824005125: dt = 63 < 100 at DIO1, DIO5!
2.824006063: dt = 63 < 100 at DIO3!
2.824014813: dt = 63 < 100 at NDAC, NRFD, DAV!
2.824018250: dt = 62 < 100 at NRFD!
2.824018750: dt = 62 < 100 at DAV, EOI!
2.824019563: dt = 63 < 100 at SRQ!
ATN change while low DAV at 2.824021437s!
2.824021500: dt = 63 < 100 at ATN!
2.824021563: dt = 63 < 100 at ATN!
2.829793750: dt = 62 < 100 at SRQ!
2.830010000: dt = 63 < 100 at DIO1, DIO5, SRQ!
2.830019062: dt = 62 < 100 at DIO1, DIO5, SRQ!
2.830019125: dt = 63 < 100 at DIO1, DIO5, SRQ!
2.830019188: dt = 63 < 100 at DIO1, DIO5, SRQ!
2.830019625: dt = 63 < 100 at DIO1, DIO5, SRQ!
2.830035500: dt = 63 < 100 at DIO1!
2.830035562: dt = 62 < 100 at DIO1!
2.830035625: dt = 63 < 100 at DIO1, DIO5, SRQ!
2.830035688: dt = 63 < 100 at DIO1!
2.830035750: dt = 62 < 100 at DIO1!
2.830052000: dt = 63 < 100 at DIO1, DIO5, SRQ!
2.830052438: dt = 63 < 100 at DIO1!
2.830068812: dt = 62 < 100 at DIO1!
2.830071063: dt = 63 < 100 at DIO1, DIO5, SRQ!
2.830091250: dt = 63 < 100 at DIO1!
2.830094375: dt = 63 < 100 at DIO1!
2.830101187: dt = 62 < 100 at DIO1, DIO5, SRQ!
2.830101250: dt = 63 < 100 at DIO1, DIO5, SRQ!
2.830101313: dt = 63 < 100 at DIO1, DIO5, SRQ!
2.830111688: dt = 63 < 100 at DIO1!
2.830114125: dt = 63 < 100 at DIO1, DIO4, DIO5, SRQ!
2.830116312: dt = 62 < 100 at DIO1, DIO5, SRQ!
2.830117438: dt = 63 < 100 at DIO1, DIO5, SRQ!
2.830117500: dt = 62 < 100 at DIO1, DIO5, SRQ!
2.830117562: dt = 62 < 100 at DIO1, DIO5, SRQ!
2.830117625: dt = 63 < 100 at DIO1, DIO5, SRQ!
2.830117688: dt = 63 < 100 at DIO1, DIO5, SRQ!
2.830117875: dt = 62 < 100 at DIO1, DIO5!
2.830117937: dt = 62 < 100 at DIO1, DIO5!
2.830118000: dt = 63 < 100 at DIO1, DIO5, SRQ!
2.830125000: dt = 63 < 100 at DIO1!
2.830131812: dt = 62 < 100 at SRQ!
2.830133813: dt = 63 < 100 at DIO1, DIO5, SRQ!
2.830133875: dt = 62 < 100 at DIO1, DIO5, SRQ!
2.830133937: dt = 62 < 100 at DIO1, DIO5, SRQ!
2.830134250: dt = 62 < 100 at DIO1, DIO5, SRQ!
2.830134312: dt = 62 < 100 at DIO1, DIO5, SRQ!
2.830134375: dt = 63 < 100 at DIO1, DIO5, SRQ!
2.830135500: dt = 62 < 100 at DIO1!
2.830135875: dt = 62 < 100 at DIO1!
2.830137875: dt = 63 < 100 at DIO1!
2.830141125: dt = 62 < 100 at DIO1!
2.830142063: dt = 63 < 100 at DIO1, DIO5, SRQ!
2.830142625: dt = 63 < 100 at DIO1!
2.830143625: dt = 63 < 100 at DIO1!
2.830145125: dt = 62 < 100 at DIO1, DIO5!
2.830145750: dt = 63 < 100 at DIO1, DIO5, SRQ!
2.830146500: dt = 63 < 100 at DIO1!
2.830146562: dt = 62 < 100 at DIO1!
2.830146625: dt = 63 < 100 at DIO1!
2.830148312: dt = 62 < 100 at DIO1, DIO5, SRQ!
2.830148500: dt = 62 < 100 at DIO1, DIO5!
2.830149125: dt = 63 < 100 at DIO1!
2.830149375: dt = 62 < 100 at DIO1, DIO5!
2.830149562: dt = 62 < 100 at DIO1!
2.830149625: dt = 63 < 100 at DIO1!
2.830149688: dt = 63 < 100 at DIO1!
2.830149750: dt = 62 < 100 at DIO1!
2.830149813: dt = 63 < 100 at DIO1!
2.830150188: dt = 63 < 100 at DIO5!
2.830150250: dt = 62 < 100 at DIO5!
2.830150437: dt = 62 < 100 at DIO1, DIO5, SRQ!
2.830150500: dt = 63 < 100 at DIO1, DIO2, DIO3, DIO4, DIO5, SRQ!
2.830150563: dt = 63 < 100 at DIO1, DIO2, DIO4, DIO5, SRQ!
2.830150625: dt = 62 < 100 at DIO1, DIO2, DIO4, DIO5, SRQ!
2.830150688: dt = 63 < 100 at DIO1!
2.830150750: dt = 62 < 100 at DIO1!
2.830150938: dt = 63 < 100 at DIO1, DIO5, SRQ!
2.830151000: dt = 62 < 100 at DIO1, DIO5, SRQ!
2.830151063: dt = 63 < 100 at DIO1, DIO5, SRQ!
2.830151375: dt = 63 < 100 at DIO1!
2.830152250: dt = 63 < 100 at DIO1!
2.830152437: dt = 62 < 100 at DIO1, DIO5!
2.830153500: dt = 63 < 100 at DIO1, DIO5, SRQ!
2.830153563: dt = 63 < 100 at DIO1!
2.830153625: dt = 62 < 100 at DIO1!
2.830155813: dt = 63 < 100 at DIO1, DIO5!
2.830157312: dt = 62 < 100 at DIO4!
2.830157812: dt = 62 < 100 at DIO5!
2.830158500: dt = 62 < 100 at DIO4!
2.830159375: dt = 62 < 100 at DIO1!
2.830159937: dt = 62 < 100 at DIO1!
2.830162313: dt = 63 < 100 at DIO1, DIO5!
2.830162375: dt = 62 < 100 at DIO1!
2.830165562: dt = 62 < 100 at DIO1!
2.830166563: dt = 63 < 100 at DIO1, DIO4, DIO5, SRQ!
2.830166625: dt = 62 < 100 at DIO1, DIO4, DIO5, SRQ!
2.830166687: dt = 62 < 100 at DIO1, DIO4, DIO5, SRQ!
2.830167000: dt = 62 < 100 at DIO1, DIO5, SRQ!
2.830167063: dt = 63 < 100 at DIO1, DIO5, SRQ!
2.830167125: dt = 62 < 100 at DIO1, DIO2, DIO3, DIO4, DIO5, SRQ!
2.830167187: dt = 62 < 100 at DIO1, DIO5, SRQ!
2.830167250: dt = 63 < 100 at SRQ!
2.830167875: dt = 62 < 100 at DIO1, DIO5, SRQ!
2.830167938: dt = 63 < 100 at DIO1, DIO5!
2.830168625: dt = 63 < 100 at DIO1!
2.830169875: dt = 63 < 100 at DIO1, DIO5!
2.830170875: dt = 62 < 100 at DIO1!
2.830172500: dt = 63 < 100 at DIO2, DIO3, DIO4!
2.830172688: dt = 63 < 100 at DIO1, DIO5!
2.830172875: dt = 63 < 100 at DIO1!
2.830173875: dt = 63 < 100 at DIO5!
2.830174625: dt = 63 < 100 at DIO1!
2.830174813: dt = 63 < 100 at DIO1!
2.830176188: dt = 63 < 100 at DIO1, DIO5!
2.830176500: dt = 62 < 100 at SRQ!
2.830176750: dt = 63 < 100 at DIO5, SRQ!
2.830178437: dt = 62 < 100 at DIO1, DIO5!
2.830178500: dt = 63 < 100 at DIO1, DIO5!
2.830178750: dt = 62 < 100 at DIO5!
2.830178812: dt = 62 < 100 at DIO5!
2.830179438: dt = 63 < 100 at DIO1, DIO5!
2.830179500: dt = 62 < 100 at DIO1, DIO5!
2.830179875: dt = 63 < 100 at DIO5!
2.830179938: dt = 63 < 100 at DIO5!
2.830180000: dt = 62 < 100 at DIO1, DIO5!
2.830180063: dt = 63 < 100 at DIO1, DIO5!
2.830180375: dt = 62 < 100 at DIO5!
2.830180438: dt = 63 < 100 at DIO1, DIO5!
2.830180687: dt = 62 < 100 at DIO5!
2.830180750: dt = 63 < 100 at DIO5!
2.830180813: dt = 63 < 100 at DIO1, DIO5!
2.830180875: dt = 62 < 100 at DIO5!
2.830181313: dt = 63 < 100 at SRQ!
2.830181375: dt = 62 < 100 at DIO5!
2.830181437: dt = 62 < 100 at DIO5!
2.830181500: dt = 63 < 100 at DIO1!
2.830181625: dt = 63 < 100 at DIO5!
2.830181688: dt = 63 < 100 at DIO1, DIO5!
2.830182188: dt = 63 < 100 at SRQ!
2.830182375: dt = 62 < 100 at SRQ!
2.830182687: dt = 62 < 100 at DIO5, SRQ!
2.830182875: dt = 63 < 100 at DIO1, DIO2, DIO3, DIO4, DIO5, SRQ!
2.830182938: dt = 63 < 100 at DIO1, DIO2, DIO3, DIO4, DIO5, SRQ!
2.830183000: dt = 62 < 100 at DIO1, DIO2, DIO3, DIO4, DIO5, SRQ!
2.830183063: dt = 63 < 100 at DIO1, DIO2, DIO3, DIO4, DIO5, SRQ!
2.830183125: dt = 62 < 100 at DIO1, DIO2, DIO3, DIO4, DIO5, SRQ!
2.830183187: dt = 62 < 100 at DIO1, DIO5, SRQ!
2.830183250: dt = 63 < 100 at DIO5, SRQ!
2.830183375: dt = 63 < 100 at DIO1!
2.830183438: dt = 63 < 100 at DIO1, DIO2, DIO3, DIO4, DIO5, SRQ!
2.830183500: dt = 62 < 100 at DIO1, DIO2, DIO4, DIO5, SRQ!
2.830183562: dt = 62 < 100 at DIO1, DIO2, DIO4, DIO5, SRQ!
2.830183625: dt = 63 < 100 at DIO1, DIO5, SRQ!
2.830183687: dt = 62 < 100 at DIO1, DIO5, SRQ!
2.830183875: dt = 62 < 100 at DIO1!
2.830183938: dt = 63 < 100 at DIO1!
2.830184000: dt = 62 < 100 at DIO1, DIO5, SRQ!
2.830184062: dt = 62 < 100 at DIO1, DIO5!
2.830184188: dt = 63 < 100 at SRQ!
2.830184250: dt = 62 < 100 at SRQ!
2.830184313: dt = 63 < 100 at SRQ!
2.830184562: dt = 62 < 100 at DIO1!
2.830184625: dt = 63 < 100 at DIO1, DIO5!
2.830184688: dt = 63 < 100 at DIO1, DIO5!
2.830184750: dt = 62 < 100 at SRQ!
2.830184937: dt = 62 < 100 at SRQ!
2.830185000: dt = 63 < 100 at SRQ!
2.830185500: dt = 63 < 100 at SRQ!
2.830185563: dt = 63 < 100 at SRQ!
2.830185625: dt = 62 < 100 at SRQ!
2.830185688: dt = 63 < 100 at SRQ!
2.830185750: dt = 62 < 100 at SRQ!
2.830185812: dt = 62 < 100 at SRQ!
2.830185875: dt = 63 < 100 at SRQ!
2.830186125: dt = 62 < 100 at SRQ!
2.830186187: dt = 62 < 100 at SRQ!
2.830186250: dt = 63 < 100 at SRQ!
2.830186312: dt = 62 < 100 at SRQ!
2.830186375: dt = 63 < 100 at SRQ!
2.830186500: dt = 62 < 100 at DIO1, DIO5!
2.830187000: dt = 62 < 100 at SRQ!
2.830187562: dt = 62 < 100 at SRQ!
2.830187875: dt = 62 < 100 at SRQ!
2.830188188: dt = 63 < 100 at SRQ!
2.830188437: dt = 62 < 100 at SRQ!
2.830188500: dt = 63 < 100 at SRQ!
2.830189438: dt = 63 < 100 at SRQ!
2.830190313: dt = 63 < 100 at SRQ!
2.830190375: dt = 62 < 100 at SRQ!
2.830190688: dt = 63 < 100 at SRQ!
2.830190937: dt = 62 < 100 at SRQ!
2.830191125: dt = 63 < 100 at SRQ!
2.830191188: dt = 63 < 100 at SRQ!
2.830191250: dt = 62 < 100 at SRQ!
2.830191500: dt = 63 < 100 at SRQ!
2.830191563: dt = 63 < 100 at SRQ!
2.830191625: dt = 62 < 100 at DIO1, DIO5!
2.830191750: dt = 62 < 100 at SRQ!
2.830191812: dt = 62 < 100 at SRQ!
2.830191875: dt = 63 < 100 at SRQ!
2.830191937: dt = 62 < 100 at SRQ!
2.830192000: dt = 63 < 100 at SRQ!
2.830192063: dt = 63 < 100 at SRQ!
2.830192938: dt = 63 < 100 at DIO1, DIO5, SRQ!
2.830193187: dt = 62 < 100 at DIO5!
2.830193250: dt = 63 < 100 at DIO5!
2.830193875: dt = 62 < 100 at DIO1, DIO5!
2.830194125: dt = 63 < 100 at DIO5!
2.830194188: dt = 63 < 100 at DIO5, SRQ!
2.830194250: dt = 62 < 100 at DIO1, DIO5!
2.830194313: dt = 63 < 100 at DIO1, DIO5!
2.830194375: dt = 62 < 100 at DIO1, DIO5!
2.830194563: dt = 63 < 100 at DIO1, DIO5!
2.830194750: dt = 62 < 100 at DIO1!
2.830194937: dt = 62 < 100 at DIO1!
2.830195000: dt = 63 < 100 at DIO1, DIO5!
2.830195250: dt = 62 < 100 at DIO5!
2.830195312: dt = 62 < 100 at DIO1, DIO5!
2.830197313: dt = 63 < 100 at SRQ!
2.830197375: dt = 62 < 100 at SRQ!
2.830197437: dt = 62 < 100 at DIO1!
2.830197562: dt = 62 < 100 at DIO5!
2.830197625: dt = 63 < 100 at DIO1!
2.830197688: dt = 63 < 100 at DIO1!
2.830198000: dt = 63 < 100 at SRQ!
2.830198063: dt = 63 < 100 at SRQ!
2.830198125: dt = 62 < 100 at DIO5!
2.830198188: dt = 63 < 100 at DIO5!
2.830198250: dt = 62 < 100 at DIO1, DIO5!
2.830198312: dt = 62 < 100 at DIO1, DIO5!
2.830198625: dt = 62 < 100 at SRQ!
2.830198687: dt = 62 < 100 at DIO1, DIO5, SRQ!
2.830198750: dt = 63 < 100 at DIO5, SRQ!
2.830198812: dt = 62 < 100 at DIO5!
2.830199125: dt = 62 < 100 at DIO1, DIO5, SRQ!
2.830199187: dt = 62 < 100 at DIO1, DIO5, SRQ!
2.830199250: dt = 63 < 100 at DIO1, DIO5, SRQ!
2.830199438: dt = 63 < 100 at DIO1, DIO4, DIO5, SRQ!
2.830199500: dt = 62 < 100 at DIO1, DIO4, DIO5, SRQ!
2.830199562: dt = 62 < 100 at DIO1, DIO2, DIO3, DIO4, DIO5, SRQ!
2.830199625: dt = 63 < 100 at DIO1, DIO4, DIO5, SRQ!
2.830199687: dt = 62 < 100 at DIO4, DIO5, SRQ!
2.830199750: dt = 63 < 100 at DIO5!
2.830199875: dt = 62 < 100 at SRQ!
2.830199938: dt = 63 < 100 at DIO1, DIO5!
2.830200000: dt = 62 < 100 at DIO1, DIO5!
2.830200625: dt = 63 < 100 at DIO2, DIO3!
2.830201000: dt = 63 < 100 at DIO1, DIO5!
2.830201062: dt = 62 < 100 at DIO1, DIO5!
2.830201250: dt = 62 < 100 at DIO1, DIO5!
2.830201312: dt = 62 < 100 at DIO1, DIO5!
2.830201500: dt = 63 < 100 at DIO2, DIO3, DIO4!
2.830201750: dt = 63 < 100 at SRQ!
2.830201812: dt = 62 < 100 at SRQ!
2.830201875: dt = 63 < 100 at SRQ!
2.830202187: dt = 62 < 100 at SRQ!
2.830202562: dt = 62 < 100 at DIO1!
2.830202750: dt = 63 < 100 at DIO5!
2.830203062: dt = 62 < 100 at DIO1, DIO5, SRQ!
2.830203125: dt = 63 < 100 at DIO1, SRQ!
2.830203250: dt = 63 < 100 at DIO5!
2.830203313: dt = 63 < 100 at SRQ!
2.830203688: dt = 63 < 100 at DIO5!
2.830204125: dt = 62 < 100 at SRQ!
2.830204312: dt = 62 < 100 at SRQ!
2.830204375: dt = 63 < 100 at DIO1, DIO5, SRQ!
2.830204437: dt = 62 < 100 at DIO5, SRQ!
2.830204563: dt = 63 < 100 at DIO1!
2.830204750: dt = 62 < 100 at SRQ!
2.830204813: dt = 63 < 100 at DIO5, SRQ!
2.830204875: dt = 62 < 100 at SRQ!
2.830205063: dt = 63 < 100 at SRQ!
2.830205125: dt = 62 < 100 at DIO1!
2.830205500: dt = 62 < 100 at SRQ!
2.830206313: dt = 63 < 100 at DIO1, DIO5!
2.830206500: dt = 63 < 100 at DIO1, DIO5!
2.830206562: dt = 62 < 100 at DIO1, DIO5!
2.830206625: dt = 63 < 100 at DIO1, DIO5!
2.830206937: dt = 62 < 100 at DIO5!
2.830207000: dt = 63 < 100 at DIO1, DIO5!
2.830207250: dt = 62 < 100 at DIO1, DIO5!
2.830207437: dt = 62 < 100 at DIO5!
2.830207500: dt = 63 < 100 at SRQ!
2.830207563: dt = 63 < 100 at SRQ!
2.830207625: dt = 62 < 100 at SRQ!
2.830207812: dt = 62 < 100 at DIO1, DIO5!
2.830208625: dt = 62 < 100 at SRQ!
2.830208750: dt = 63 < 100 at DIO1, DIO5!
2.830209000: dt = 62 < 100 at SRQ!
2.830209313: dt = 63 < 100 at DIO1, DIO5!
2.830209375: dt = 62 < 100 at DIO5!
2.830209438: dt = 63 < 100 at DIO5!
2.830209625: dt = 63 < 100 at DIO1!
2.830210062: dt = 62 < 100 at DIO5!
2.830210563: dt = 63 < 100 at SRQ!
2.830210812: dt = 62 < 100 at SRQ!
2.830210937: dt = 62 < 100 at DIO1, DIO5!
2.830211312: dt = 62 < 100 at SRQ!
2.830211375: dt = 63 < 100 at SRQ!
2.830211500: dt = 62 < 100 at DIO1, DIO5!
2.830211625: dt = 62 < 100 at SRQ!
2.830211687: dt = 62 < 100 at DIO1, DIO5!
2.830211938: dt = 63 < 100 at SRQ!
2.830212375: dt = 63 < 100 at DIO1, DIO5!
2.830212438: dt = 63 < 100 at DIO1, DIO5!
2.830213062: dt = 62 < 100 at DIO1!
2.830213125: dt = 63 < 100 at DIO1!
2.830213188: dt = 63 < 100 at DIO1, DIO5, SRQ!
2.830213250: dt = 62 < 100 at DIO1, DIO5, SRQ!
2.830213937: dt = 62 < 100 at SRQ!
2.830214000: dt = 63 < 100 at SRQ!
2.830214063: dt = 63 < 100 at SRQ!
2.830214125: dt = 62 < 100 at SRQ!
2.830214438: dt = 63 < 100 at SRQ!
2.830214500: dt = 62 < 100 at SRQ!
2.830214563: dt = 63 < 100 at SRQ!
2.830214625: dt = 62 < 100 at SRQ!
2.830214812: dt = 62 < 100 at SRQ!
2.830214875: dt = 63 < 100 at SRQ!
2.830214938: dt = 63 < 100 at SRQ!
2.830215000: dt = 62 < 100 at SRQ!
2.830215063: dt = 63 < 100 at SRQ!
2.830215375: dt = 62 < 100 at DIO1, DIO5!
2.830215438: dt = 63 < 100 at DIO1, DIO2, DIO3, DIO4, DIO5, SRQ!
2.830215500: dt = 62 < 100 at DIO1, DIO2, DIO3, DIO4, DIO5, SRQ!
2.830215562: dt = 62 < 100 at DIO1, DIO2, DIO3, DIO4, DIO5, SRQ!
2.830215625: dt = 63 < 100 at DIO1, DIO5, SRQ!
2.830215687: dt = 62 < 100 at DIO1, DIO5, SRQ!
2.830215875: dt = 62 < 100 at DIO1, DIO2, DIO3, DIO4, DIO5, SRQ!
2.830215937: dt = 62 < 100 at DIO1, DIO2, DIO3, DIO4, DIO5, SRQ!
2.830216000: dt = 63 < 100 at DIO1, DIO2, DIO3, DIO4, DIO5, SRQ!
2.830216062: dt = 62 < 100 at DIO1, DIO5, SRQ!
2.830216125: dt = 63 < 100 at SRQ!
2.830216313: dt = 63 < 100 at SRQ!
2.830216375: dt = 62 < 100 at DIO1, DIO5!
2.830216500: dt = 63 < 100 at DIO4!
2.830216688: dt = 63 < 100 at DIO1, DIO5, SRQ!
2.830216750: dt = 62 < 100 at DIO2, DIO4, SRQ!
2.830216875: dt = 63 < 100 at DIO1, DIO5!
2.830216937: dt = 62 < 100 at DIO1, SRQ!
2.830217000: dt = 63 < 100 at DIO1!
2.830217563: dt = 63 < 100 at SRQ!
2.830217625: dt = 62 < 100 at SRQ!
2.830218438: dt = 63 < 100 at SRQ!
2.830218500: dt = 62 < 100 at SRQ!
2.830219625: dt = 63 < 100 at SRQ!
2.830221562: dt = 62 < 100 at DIO4!
2.830222500: dt = 63 < 100 at DIO1, DIO5, SRQ!
2.830222562: dt = 62 < 100 at DIO5, SRQ!
2.830222625: dt = 63 < 100 at DIO5, SRQ!
2.830223437: dt = 62 < 100 at DIO2, DIO3, DIO4!
2.830223500: dt = 63 < 100 at DIO5, SRQ!
2.830223562: dt = 62 < 100 at DIO5, SRQ!
2.830223625: dt = 63 < 100 at DIO1, DIO5, SRQ!
2.830225125: dt = 63 < 100 at DIO2, DIO4!
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

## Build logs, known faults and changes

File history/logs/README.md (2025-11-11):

# Logs

This folder was supposed to contain sample logs of communication between the laptop and different devices like FDD or HDD.

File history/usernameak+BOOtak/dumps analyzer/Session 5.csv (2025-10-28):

Time [s] | DIO1 | DIO2 | DIO3 | DIO4 | DIO5 | DIO6 | DIO7 | DIO8 | SRQ | NDAC | ATN | NRFD | DAV | EOI
0.000000000 | 1 | 1 | 1 | 1 | 1 | 1 | 1 | 1 | 1 | 0 | 1 | 1 | 1 | 1
2.275759187 | 1 | 1 | 1 | 1 | 1 | 1 | 1 | 1 | 1 | 1 | 1 | 1 | 1 | 1
2.275759563 | 1 | 1 | 1 | 1 | 1 | 1 | 1 | 1 | 1 | 0 | 1 | 1 | 1 | 1
2.275759687 | 1 | 1 | 1 | 1 | 1 | 1 | 1 | 1 | 1 | 1 | 1 | 1 | 1 | 1
2.275761312 | 1 | 1 | 1 | 1 | 1 | 1 | 1 | 1 | 1 | 0 | 1 | 1 | 1 | 1
2.275761375 | 1 | 1 | 1 | 1 | 1 | 1 | 1 | 1 | 1 | 1 | 1 | 1 | 1 | 1
2.594917437 | 1 | 1 | 0 | 0 | 1 | 0 | 1 | 1 | 1 | 1 | 1 | 1 | 1 | 1
2.594917500 | 1 | 1 | 1 | 1 | 1 | 1 | 1 | 1 | 1 | 1 | 1 | 1 | 1 | 1
2.594926375 | 0 | 0 | 0 | 0 | 0 | 1 | 0 | 0 | 0 | 0 | 0 | 1 | 1 | 1
2.594926437 | 1 | 1 | 1 | 1 | 1 | 1 | 1 | 1 | 1 | 1 | 1 | 1 | 1 | 1
2.594929062 | 1 | 1 | 1 | 1 | 1 | 1 | 1 | 1 | 1 | 1 | 0 | 1 | 1 | 1
2.594939500 | 1 | 1 | 1 | 1 | 1 | 1 | 1 | 1 | 1 | 0 | 0 | 1 | 1 | 1
2.594939563 | 1 | 1 | 1 | 1 | 1 | 1 | 1 | 1 | 0 | 0 | 0 | 1 | 1 | 1
2.594939688 | 1 | 1 | 1 | 1 | 1 | 1 | 1 | 1 | 1 | 0 | 0 | 1 | 1 | 1
2.594953750 | 1 | 1 | 1 | 1 | 1 | 1 | 1 | 1 | 1 | 0 | 1 | 1 | 1 | 1
2.594982438 | 1 | 1 | 1 | 1 | 1 | 1 | 1 | 1 | 1 | 1 | 1 | 1 | 1 | 1
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

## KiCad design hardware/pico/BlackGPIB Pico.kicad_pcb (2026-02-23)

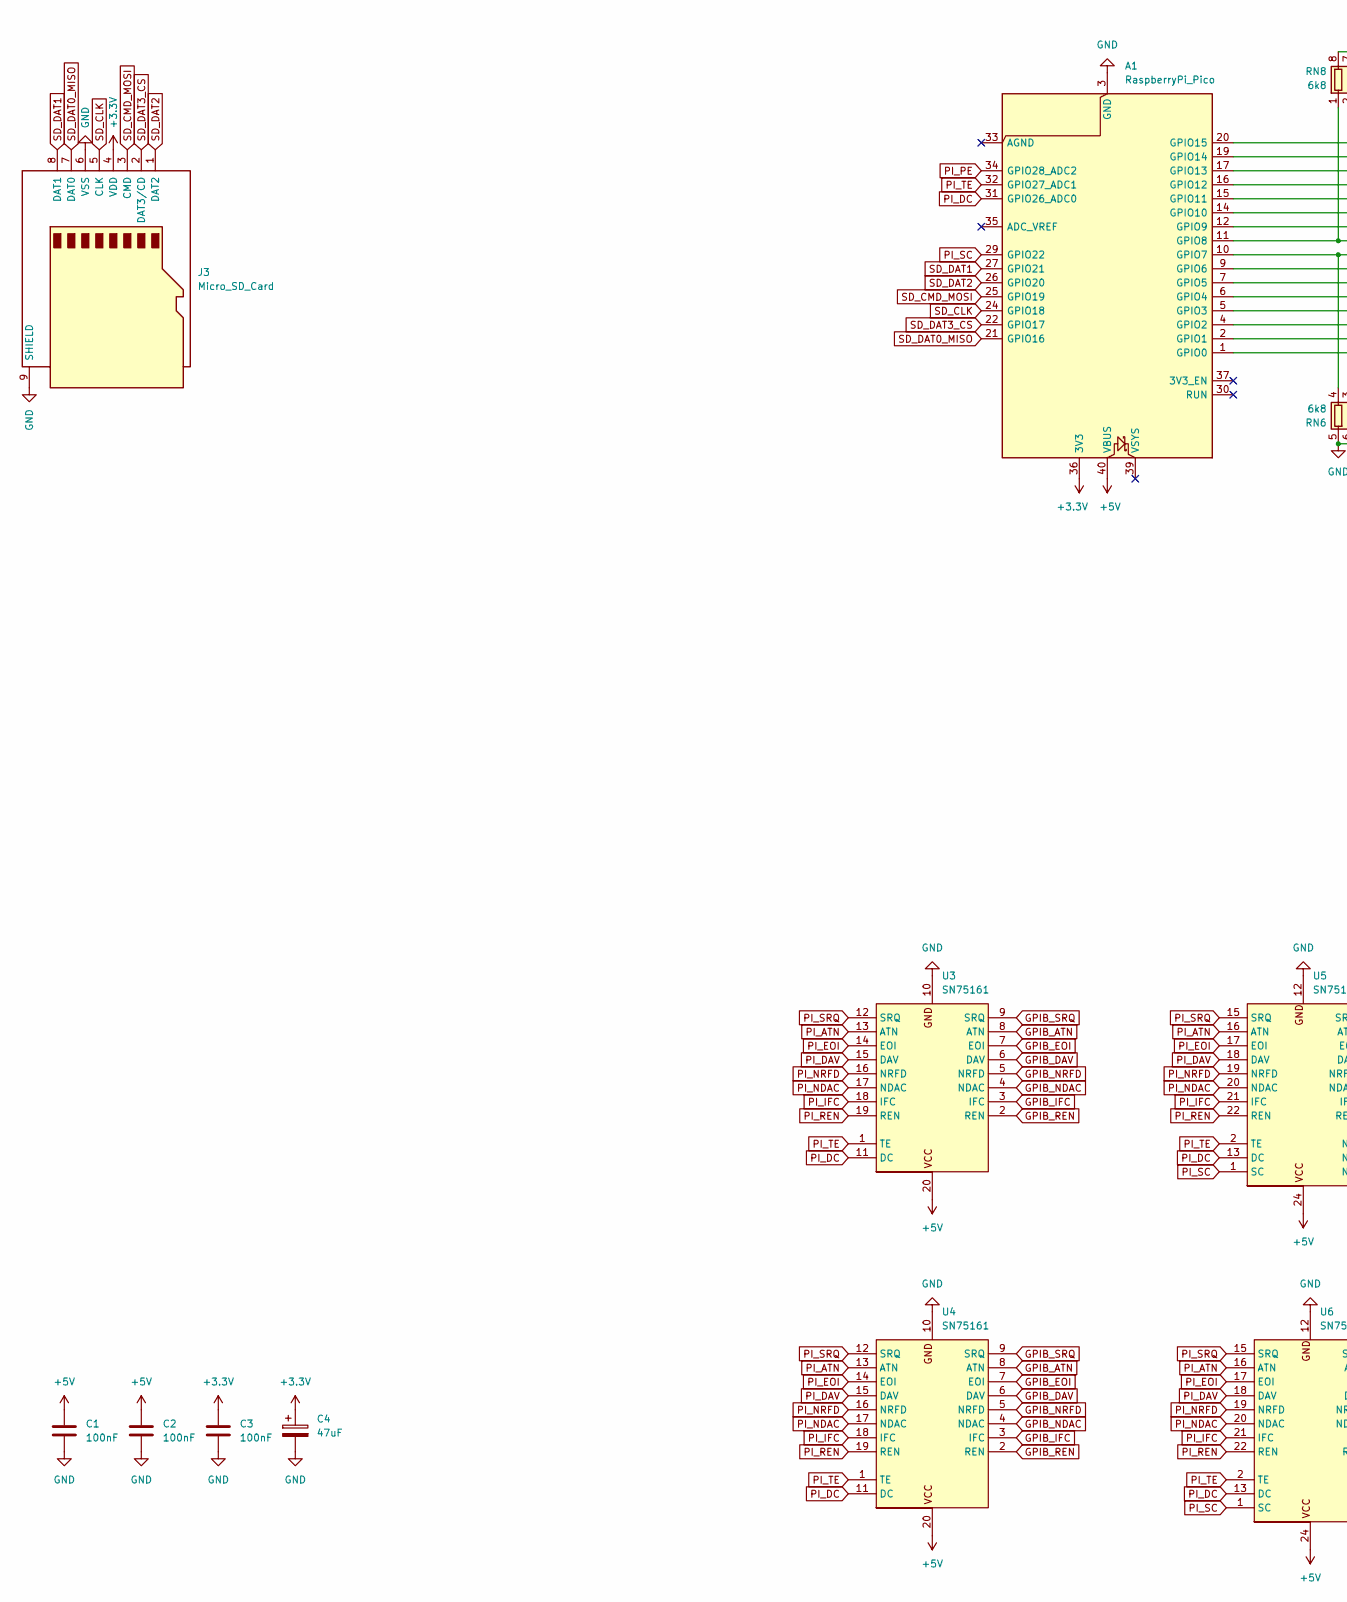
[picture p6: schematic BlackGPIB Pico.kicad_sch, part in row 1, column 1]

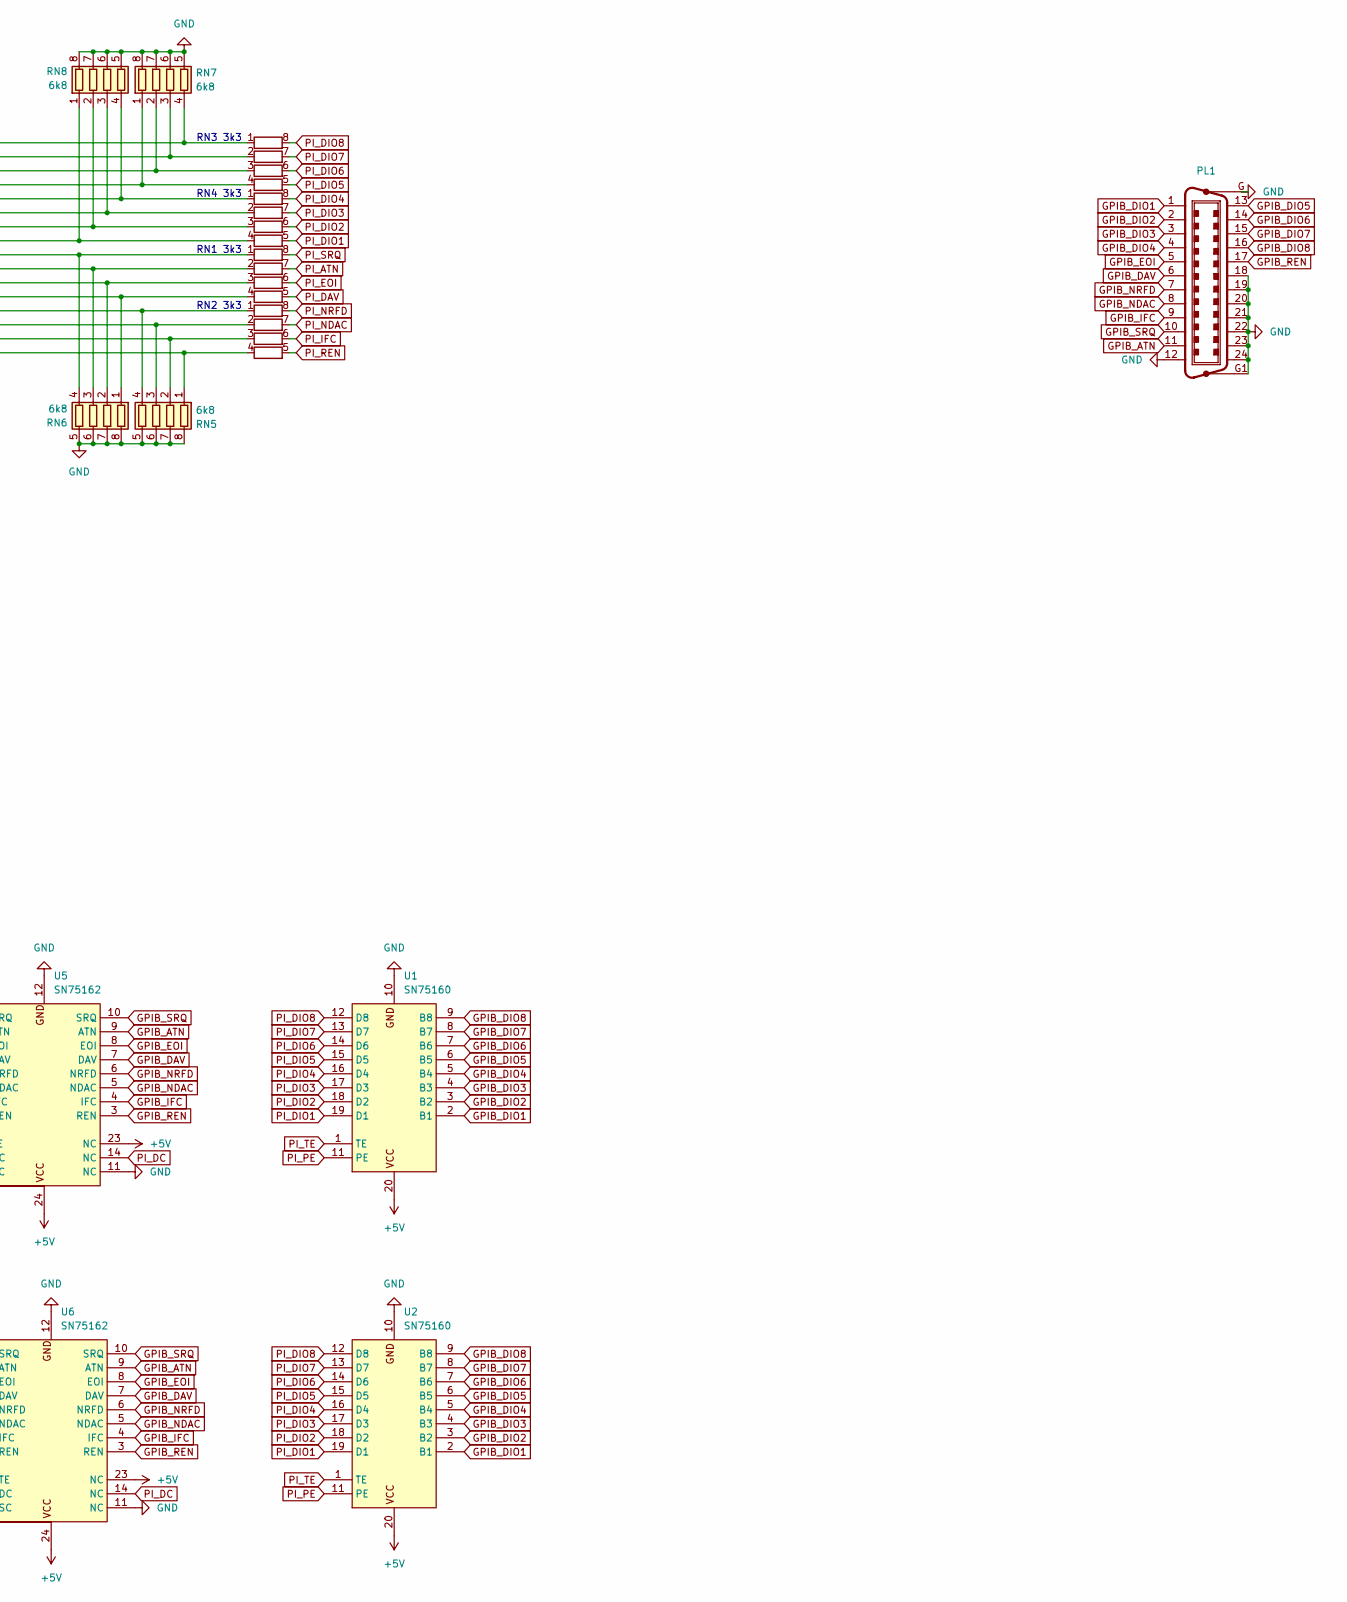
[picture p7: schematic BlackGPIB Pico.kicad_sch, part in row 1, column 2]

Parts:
A1: RaspberryPi_Pico; RaspberryPi_Pico_SMD_HandSolder
C1, C2, C3: 100nF; C_1206_3216Metric_Pad1.33x1.80mm_HandSolder
C4: 47uF; CP_EIA-6032-15_Kemet-U_HandSolder
J3: Micro_SD_Card; microSD_HC_Hirose_DM3AT-SF-PEJM5
PL1: Centronics 24; Centronics-24
RN1, RN2, RN3, RN4: 3k3; R_Array_Convex_4x1206
RN5, RN6, RN7, RN8: 6k8; R_Array_Convex_4x1206
U1: SN75160; DIP-20_W7.62mm_LongPads
U2: SN75160; SOIC-20
U3: SN75161; DIP-20_W7.62mm_LongPads
U4: SN75161; SOIC-20
U5: SN75162; DIP-24_W7.62mm_LongPads
U6: SN75162; SOIC-24

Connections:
+3.3V: A1.36 (3V3), C3.1, C4.1, J3.4 (VDD)
+5V: A1.40 (VBUS), C1.1, C2.1, U1.20 (VCC), U2.20 (VCC), U3.20 (VCC), U4.20 (VCC), U5.23 (NC), U5.24 (VCC), U6.23 (NC), U6.24 (VCC)
GND: A1.3 (GND), A1.8 (GND), A1.13 (GND), A1.18 (GND), A1.23 (GND), A1.28 (GND), A1.38 (GND), C1.2, C2.2, C3.2, C4.2, J3.6 (VSS), J3.9 (SHIELD), PL1.12, PL1.18, PL1.19, PL1.20, PL1.21, PL1.22, PL1.23, PL1.24, PL1.G, PL1.G1, RN5.5 (R4.2), RN5.6 (R3.2), RN5.7 (R2.2), RN5.8 (R1.2), RN6.5 (R4.2), RN6.6 (R3.2), RN6.7 (R2.2), RN6.8 (R1.2), RN7.5 (R4.2), RN7.6 (R3.2), RN7.7 (R2.2), RN7.8 (R1.2), RN8.5 (R4.2), RN8.6 (R3.2), RN8.7 (R2.2), RN8.8 (R1.2), U1.10 (GND), U2.10 (GND), U3.10 (GND), U4.10 (GND), U5.11 (NC), U5.12 (GND), U6.11 (NC), U6.12 (GND)
GPIB_ATN: PL1.11, U3.8 (ATN), U4.8 (ATN), U5.9 (ATN), U6.9 (ATN)
GPIB_DAV: PL1.6, U3.6 (DAV), U4.6 (DAV), U5.7 (DAV), U6.7 (DAV)
GPIB_DIO1: PL1.1, U1.2 (B1), U2.2 (B1)
GPIB_DIO2: PL1.2, U1.3 (B2), U2.3 (B2)
GPIB_DIO3: PL1.3, U1.4 (B3), U2.4 (B3)
GPIB_DIO4: PL1.4, U1.5 (B4), U2.5 (B4)
GPIB_DIO5: PL1.13, U1.6 (B5), U2.6 (B5)
GPIB_DIO6: PL1.14, U1.7 (B6), U2.7 (B6)
GPIB_DIO7: PL1.15, U1.8 (B7), U2.8 (B7)
GPIB_DIO8: PL1.16, U1.9 (B8), U2.9 (B8)
GPIB_EOI: PL1.5, U3.7 (EOI), U4.7 (EOI), U5.8 (EOI), U6.8 (EOI)
GPIB_IFC: PL1.9, U3.3 (IFC), U4.3 (IFC), U5.4 (IFC), U6.4 (IFC)
GPIB_NDAC: PL1.8, U3.4 (NDAC), U4.4 (NDAC), U5.5 (NDAC), U6.5 (NDAC)
GPIB_NRFD: PL1.7, U3.5 (NRFD), U4.5 (NRFD), U5.6 (NRFD), U6.6 (NRFD)
GPIB_REN: PL1.17, U3.2 (REN), U4.2 (REN), U5.3 (REN), U6.3 (REN)
GPIB_SRQ: PL1.10, U3.9 (SRQ), U4.9 (SRQ), U5.10 (SRQ), U6.10 (SRQ)
unnamed: A1.1 (GPIO0), RN2.4 (R4.1), RN5.1 (R1.1)
unnamed: A1.2 (GPIO1), RN2.3 (R3.1), RN5.2 (R2.1)
unnamed: A1.4 (GPIO2), RN2.2 (R2.1), RN5.3 (R3.1)
unnamed: A1.5 (GPIO3), RN2.1 (R1.1), RN5.4 (R4.1)
unnamed: A1.6 (GPIO4), RN1.4 (R4.1), RN6.1 (R1.1)
unnamed: A1.7 (GPIO5), RN1.3 (R3.1), RN6.2 (R2.1)
unnamed: A1.9 (GPIO6), RN1.2 (R2.1), RN6.3 (R3.1)
unnamed: A1.10 (GPIO7), RN1.1 (R1.1), RN6.4 (R4.1)
unnamed: A1.11 (GPIO8), RN4.4 (R4.1), RN8.1 (R1.1)
unnamed: A1.12 (GPIO9), RN4.3 (R3.1), RN8.2 (R2.1)
unnamed: A1.14 (GPIO10), RN4.2 (R2.1), RN8.3 (R3.1)
unnamed: A1.15 (GPIO11), RN4.1 (R1.1), RN8.4 (R4.1)
unnamed: A1.16 (GPIO12), RN3.4 (R4.1), RN7.1 (R1.1)
unnamed: A1.17 (GPIO13), RN3.3 (R3.1), RN7.2 (R2.1)
unnamed: A1.19 (GPIO14), RN3.2 (R2.1), RN7.3 (R3.1)
unnamed: A1.20 (GPIO15), RN3.1 (R1.1), RN7.4 (R4.1)
PI_ATN: RN1.7 (R2.2), U3.13 (ATN), U4.13 (ATN), U5.16 (ATN), U6.16 (ATN)
PI_DAV: RN1.5 (R4.2), U3.15 (DAV), U4.15 (DAV), U5.18 (DAV), U6.18 (DAV)
PI_DC: A1.31 (GPIO26_ADC0), U3.11 (DC), U4.11 (DC), U5.13 (DC), U5.14 (NC), U6.13 (DC), U6.14 (NC)
PI_DIO1: RN4.5 (R4.2), U1.19 (D1), U2.19 (D1)
PI_DIO2: RN4.6 (R3.2), U1.18 (D2), U2.18 (D2)
PI_DIO3: RN4.7 (R2.2), U1.17 (D3), U2.17 (D3)
PI_DIO4: RN4.8 (R1.2), U1.16 (D4), U2.16 (D4)
PI_DIO5: RN3.5 (R4.2), U1.15 (D5), U2.15 (D5)
PI_DIO6: RN3.6 (R3.2), U1.14 (D6), U2.14 (D6)
PI_DIO7: RN3.7 (R2.2), U1.13 (D7), U2.13 (D7)
PI_DIO8: RN3.8 (R1.2), U1.12 (D8), U2.12 (D8)
PI_EOI: RN1.6 (R3.2), U3.14 (EOI), U4.14 (EOI), U5.17 (EOI), U6.17 (EOI)
PI_IFC: RN2.6 (R3.2), U3.18 (IFC), U4.18 (IFC), U5.21 (IFC), U6.21 (IFC)
PI_NDAC: RN2.7 (R2.2), U3.17 (NDAC), U4.17 (NDAC), U5.20 (NDAC), U6.20 (NDAC)
PI_NRFD: RN2.8 (R1.2), U3.16 (NRFD), U4.16 (NRFD), U5.19 (NRFD), U6.19 (NRFD)
PI_PE: A1.34 (GPIO28_ADC2), U1.11 (PE), U2.11 (PE)
PI_REN: RN2.5 (R4.2), U3.19 (REN), U4.19 (REN), U5.22 (REN), U6.22 (REN)
PI_SC: A1.29 (GPIO22), U5.1 (SC), U6.1 (SC)
PI_SRQ: RN1.8 (R1.2), U3.12 (SRQ), U4.12 (SRQ), U5.15 (SRQ), U6.15 (SRQ)
PI_TE: A1.32 (GPIO27_ADC1), U1.1 (TE), U2.1 (TE), U3.1 (TE), U4.1 (TE), U5.2 (TE), U6.2 (TE)
SD_CLK: A1.24 (GPIO18), J3.5 (CLK)
SD_CMD_MOSI: A1.25 (GPIO19), J3.3 (CMD)
SD_DAT0_MISO: A1.21 (GPIO16), J3.7 (DAT0)
SD_DAT1: A1.27 (GPIO21), J3.8 (DAT1)
SD_DAT2: A1.26 (GPIO20), J3.1 (DAT2)
SD_DAT3_CS: A1.22 (GPIO17), J3.2 (DAT3/CD)

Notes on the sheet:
RN2 3k3
RN3 3k3
RN4 3k3
RN1 3k3

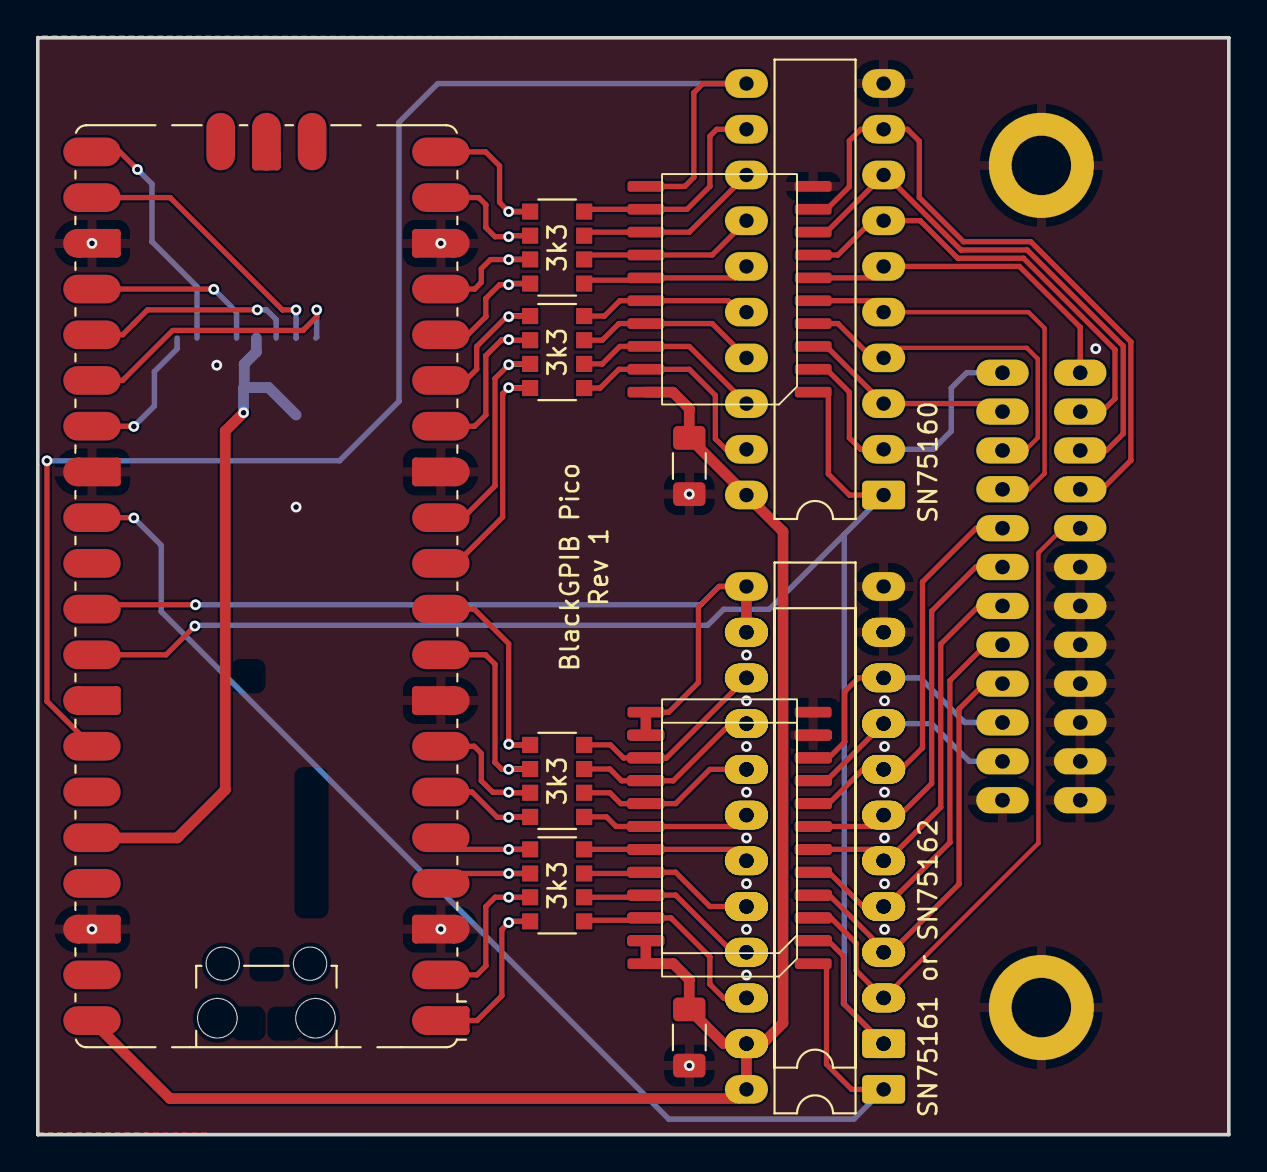
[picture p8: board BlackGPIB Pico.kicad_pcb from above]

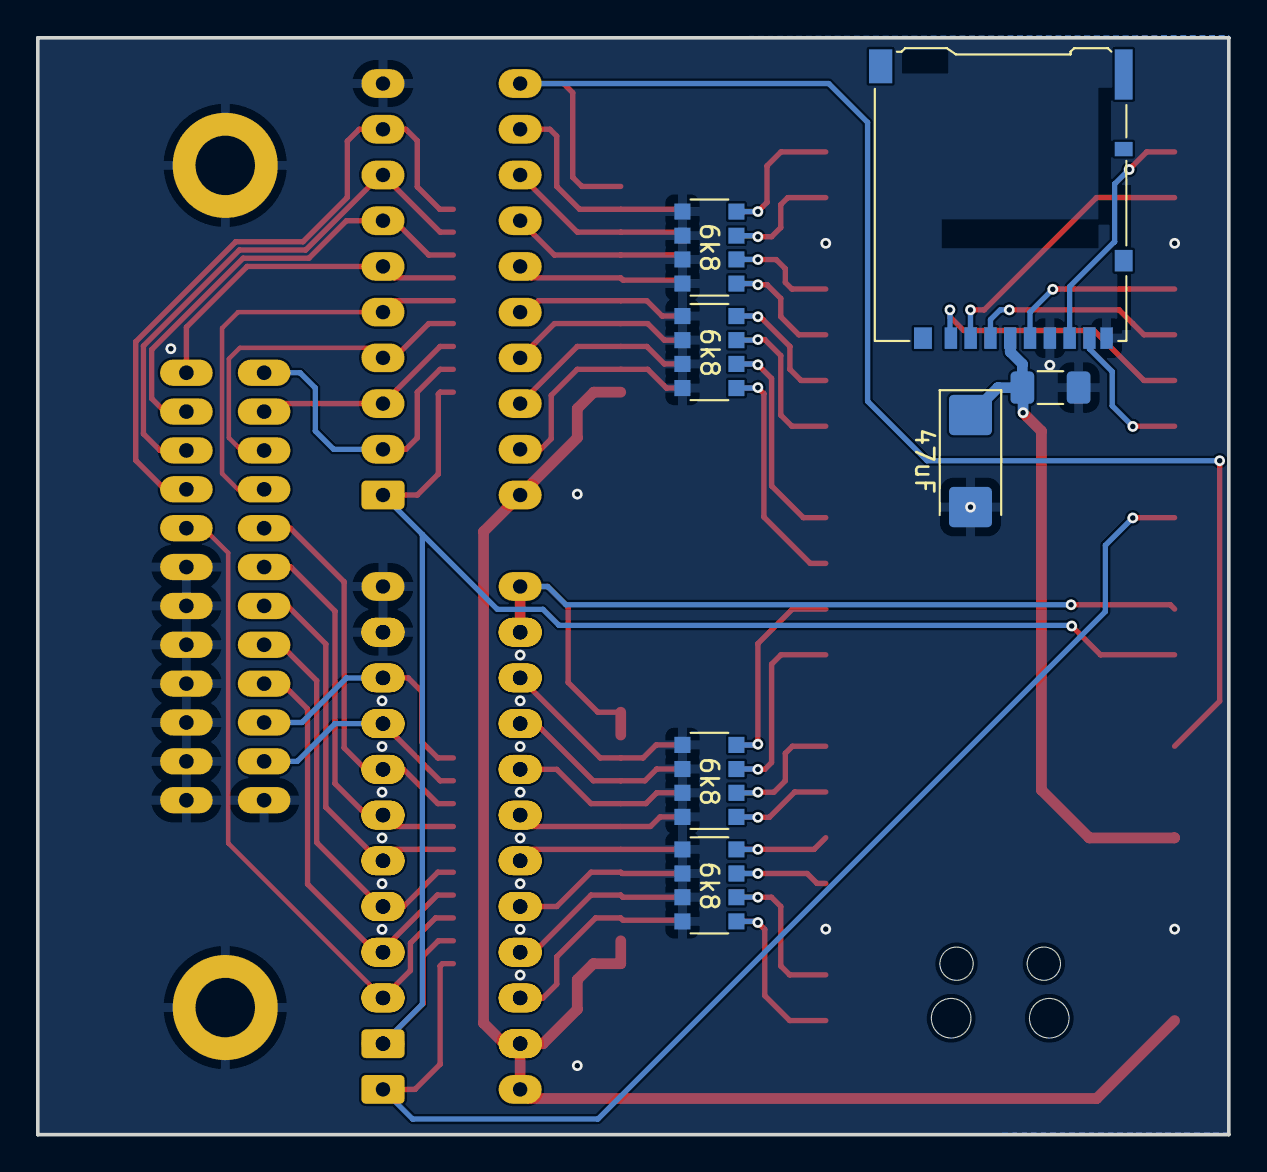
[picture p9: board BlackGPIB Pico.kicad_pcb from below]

Board: 2 copper layers, 66.2 x 60.9 mm, 21 parts (7 on the bottom side), 61 nets.

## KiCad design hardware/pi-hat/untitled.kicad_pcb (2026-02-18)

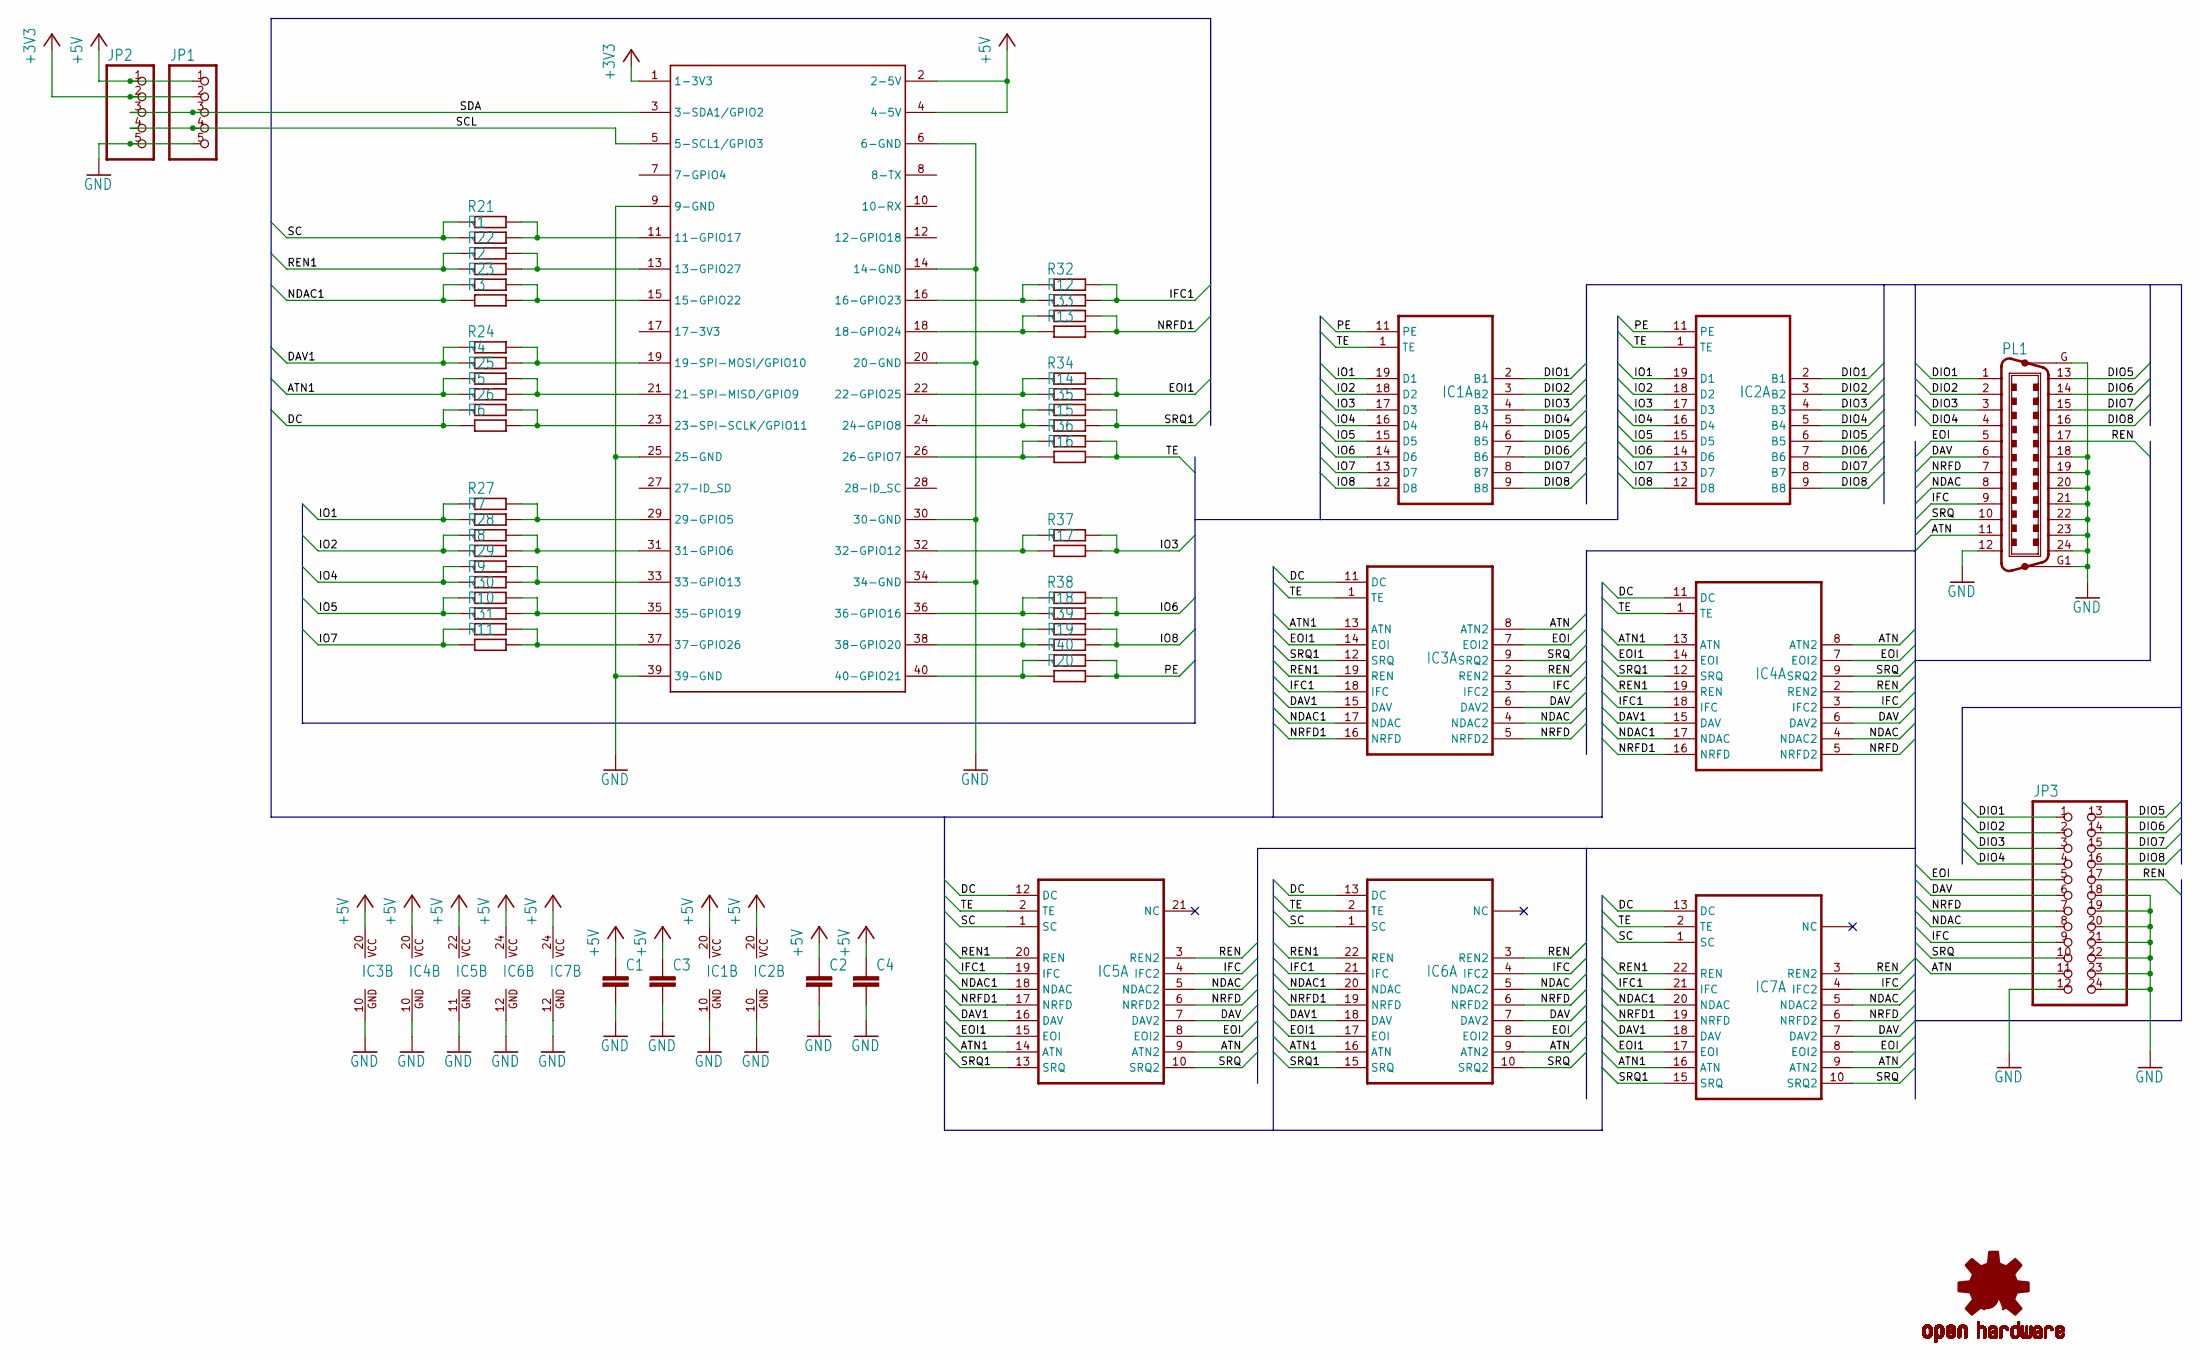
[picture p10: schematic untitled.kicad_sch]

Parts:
C1, C2: C-EUC0805; C0805
C3, C4: C-EU050-024X044; C050-024X044
IC1: 75160P; DIL20
IC2: 75160SO; SO20L
IC3: 75161P; DIL20
IC4: 75161SO; SO20L
IC5: 75162P; DIL22-3
IC6: 75162; DIL24-3
IC7: 75162SO24; SOIC127P1030X265-24N
JP1, JP2: PINHD-1X5; 1X05
JP3: GPIB-PINHD-2X12
LOGO2: OSHW-LOGOS; OSHW-LOGO-S
PL1: C24HP; 24HP
R1, R2, R3, R4, R5, R6, R7, R8, R9, R10, R11, R12, R13, R14, R15, R16, R17, R18, R19, R20: 3k; R0805
R21, R22, R23, R24, R25, R26, R27, R28, R29, R30, R31, R32, R33, R34, R35, R36, R37, R38, R39, R40: 3k; 0204_7
U$2: RASPBERRY-PI+HEADERONLY; RASPBERRY-PI-PLUS-HEADERONLY

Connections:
+3V3: JP1.2, JP2.2, U$2.1 (1-3V3)
+5V: C1.1, C2.1, C3.1, C4.1, IC1.20 (VCC), IC2.20 (VCC), IC3.20 (VCC), IC4.20 (VCC), IC5.22 (VCC), IC6.24 (VCC), IC7.24 (VCC), JP1.1, JP2.1, U$2.2 (2-5V), U$2.4 (4-5V)
/ATN: IC3.8 (ATN2), IC4.8 (ATN2), IC5.9 (ATN2), IC6.9 (ATN2), IC7.9 (ATN2), JP3.11, PL1.11
/ATN1: IC3.13 (ATN), IC4.13 (ATN), IC5.14 (ATN), IC6.16 (ATN), IC7.16 (ATN), R5.1, R25.1
/DAV: IC3.6 (DAV2), IC4.6 (DAV2), IC5.7 (DAV2), IC6.7 (DAV2), IC7.7 (DAV2), JP3.6, PL1.6
/DAV1: IC3.15 (DAV), IC4.15 (DAV), IC5.16 (DAV), IC6.18 (DAV), IC7.18 (DAV), R4.1, R24.1
/DC: IC3.11 (DC), IC4.11 (DC), IC5.12 (DC), IC6.13 (DC), IC7.13 (DC), R6.1, R26.1
/DIO1: IC1.2 (B1), IC2.2 (B1), JP3.1, PL1.1
/DIO2: IC1.3 (B2), IC2.3 (B2), JP3.2, PL1.2
/DIO3: IC1.4 (B3), IC2.4 (B3), JP3.3, PL1.3
/DIO4: IC1.5 (B4), IC2.5 (B4), JP3.4, PL1.4
/DIO5: IC1.6 (B5), IC2.6 (B5), JP3.13, PL1.13
/DIO6: IC1.7 (B6), IC2.7 (B6), JP3.14, PL1.14
/DIO7: IC1.8 (B7), IC2.8 (B7), JP3.15, PL1.15
/DIO8: IC1.9 (B8), IC2.9 (B8), JP3.16, PL1.16
/EOI: IC3.7 (EOI2), IC4.7 (EOI2), IC5.8 (EOI2), IC6.8 (EOI2), IC7.8 (EOI2), JP3.5, PL1.5
/EOI1: IC3.14 (EOI), IC4.14 (EOI), IC5.15 (EOI), IC6.17 (EOI), IC7.17 (EOI), R14.2, R34.2
/IFC: IC3.3 (IFC2), IC4.3 (IFC2), IC5.4 (IFC2), IC6.4 (IFC2), IC7.4 (IFC2), JP3.9, PL1.9
/IFC1: IC3.18 (IFC), IC4.18 (IFC), IC5.19 (IFC), IC6.21 (IFC), IC7.21 (IFC), R12.2, R32.2
/IO1: IC1.19 (D1), IC2.19 (D1), R7.1, R27.1
/IO2: IC1.18 (D2), IC2.18 (D2), R8.1, R28.1
/IO3: IC1.17 (D3), IC2.17 (D3), R17.2, R37.2
/IO4: IC1.16 (D4), IC2.16 (D4), R9.1, R29.1
/IO5: IC1.15 (D5), IC2.15 (D5), R10.1, R30.1
/IO6: IC1.14 (D6), IC2.14 (D6), R18.2, R38.2
/IO7: IC1.13 (D7), IC2.13 (D7), R11.1, R31.1
/IO8: IC1.12 (D8), IC2.12 (D8), R19.2, R39.2
/NDAC: IC3.4 (NDAC2), IC4.4 (NDAC2), IC5.5 (NDAC2), IC6.5 (NDAC2), IC7.5 (NDAC2), JP3.8, PL1.8
/NDAC1: IC3.17 (NDAC), IC4.17 (NDAC), IC5.18 (NDAC), IC6.20 (NDAC), IC7.20 (NDAC), R3.1, R23.1
/NRFD: IC3.5 (NRFD2), IC4.5 (NRFD2), IC5.6 (NRFD2), IC6.6 (NRFD2), IC7.6 (NRFD2), JP3.7, PL1.7
/NRFD1: IC3.16 (NRFD), IC4.16 (NRFD), IC5.17 (NRFD), IC6.19 (NRFD), IC7.19 (NRFD), R13.2, R33.2
/PE: IC1.11 (PE), IC2.11 (PE), R20.2, R40.2
/REN: IC3.2 (REN2), IC4.2 (REN2), IC5.3 (REN2), IC6.3 (REN2), IC7.3 (REN2), JP3.17, PL1.17
/REN1: IC3.19 (REN), IC4.19 (REN), IC5.20 (REN), IC6.22 (REN), IC7.22 (REN), R2.1, R22.1
/SC: IC5.1 (SC), IC6.1 (SC), IC7.1 (SC), R1.1, R21.1
/SCL: JP1.4, JP2.4, U$2.5 (5-SCL1/GPIO3)
/SDA: JP1.3, JP2.3, U$2.3 (3-SDA1/GPIO2)
/SRQ: IC3.9 (SRQ2), IC4.9 (SRQ2), IC5.10 (SRQ2), IC6.10 (SRQ2), IC7.10 (SRQ2), JP3.10, PL1.10
/SRQ1: IC3.12 (SRQ), IC4.12 (SRQ), IC5.13 (SRQ), IC6.15 (SRQ), IC7.15 (SRQ), R15.2, R35.2
/TE: IC1.1 (TE), IC2.1 (TE), IC3.1 (TE), IC4.1 (TE), IC5.2 (TE), IC6.2 (TE), IC7.2 (TE), R16.2, R36.2
GND: C1.2, C2.2, C3.2, C4.2, IC1.10 (GND), IC2.10 (GND), IC3.10 (GND), IC4.10 (GND), IC5.11 (GND), IC6.12 (GND), IC7.12 (GND), JP1.5, JP2.5, JP3.12, JP3.18, JP3.19, JP3.20, JP3.21, JP3.22, JP3.23, JP3.24, PL1.12, PL1.18, PL1.19, PL1.20, PL1.21, PL1.22, PL1.23, PL1.24, PL1.G, PL1.G1, U$2.6 (6-GND), U$2.9 (9-GND), U$2.14 (14-GND), U$2.20 (20-GND), U$2.25 (25-GND), U$2.30 (30-GND), U$2.34 (34-GND), U$2.39 (39-GND)
unnamed: R1.2, R21.2, U$2.11 (11-GPIO17)
unnamed: R2.2, R22.2, U$2.13 (13-GPIO27)
unnamed: R3.2, R23.2, U$2.15 (15-GPIO22)
unnamed: R12.1, R32.1, U$2.16 (16-GPIO23)
unnamed: R13.1, R33.1, U$2.18 (18-GPIO24)
unnamed: R4.2, R24.2, U$2.19 (19-SPI-MOSI/GPIO10)
unnamed: R5.2, R25.2, U$2.21 (21-SPI-MISO/GPIO9)
unnamed: R14.1, R34.1, U$2.22 (22-GPIO25)
unnamed: R6.2, R26.2, U$2.23 (23-SPI-SCLK/GPIO11)
unnamed: R15.1, R35.1, U$2.24 (24-GPIO8)
unnamed: R16.1, R36.1, U$2.26 (26-GPIO7)
unnamed: R7.2, R27.2, U$2.29 (29-GPIO5)
unnamed: R8.2, R28.2, U$2.31 (31-GPIO6)
unnamed: R17.1, R37.1, U$2.32 (32-GPIO12)
unnamed: R9.2, R29.2, U$2.33 (33-GPIO13)
unnamed: R10.2, R30.2, U$2.35 (35-GPIO19)
unnamed: R18.1, R38.1, U$2.36 (36-GPIO16)
unnamed: R11.2, R31.2, U$2.37 (37-GPIO26)
unnamed: R19.1, R39.1, U$2.38 (38-GPIO20)
unnamed: R20.1, R40.1, U$2.40 (40-GPIO21)

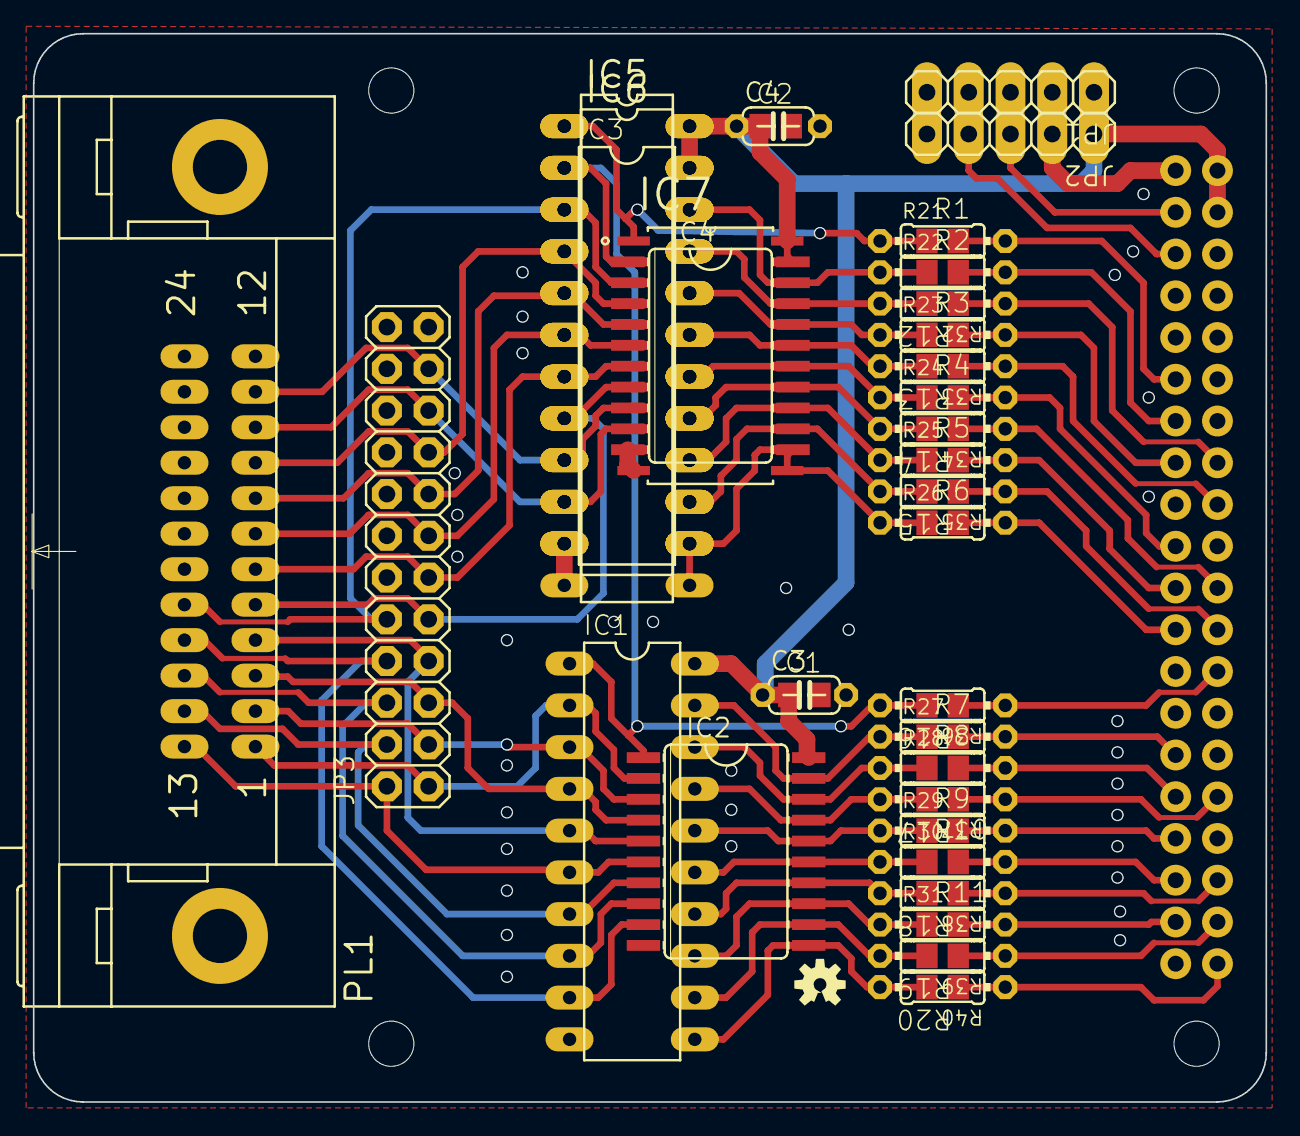
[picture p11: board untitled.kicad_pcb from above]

Board: 2 copper layers, 75.0 x 65.0 mm, 61 parts (0 on the bottom side), 61 nets.

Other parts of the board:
UNK_HOLE_0: dummyfp0
UNK_HOLE_1: dummyfp1
UNK_HOLE_2: dummyfp2
UNK_HOLE_3: dummyfp3

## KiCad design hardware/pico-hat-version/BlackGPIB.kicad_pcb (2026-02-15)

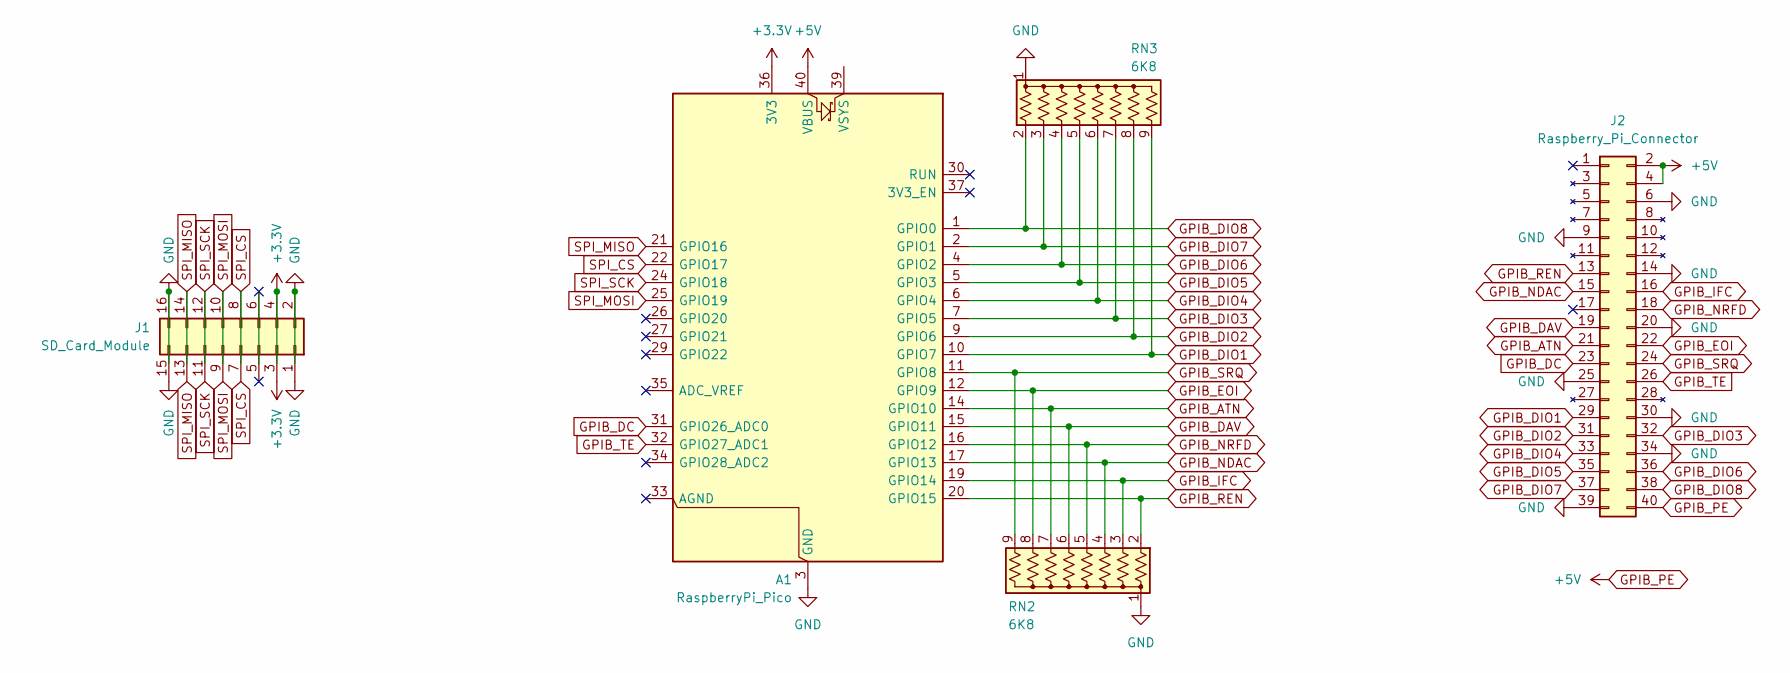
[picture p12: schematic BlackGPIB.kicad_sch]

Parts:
A1: RaspberryPi_Pico; RaspberryPi_Pico_W_SMD_HandSolder
J1: SD_Card_Module; PinHeader_2x08_P2.54mm_Vertical_SMD
J2: Raspberry_Pi_Connector; PinHeader_2x20_P2.54mm_Vertical_SMD
RN2: 6K8; PinHeader_1x09_P2.54mm_Horizontal_Right_FlipX
RN3: 6K8; PinHeader_1x09_P2.54mm_Horizontal_Right

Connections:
+3.3V: A1.36 (3V3), J1.3 (3.3V), J1.4 (3.3V)
GND: A1.3 (GND), A1.8 (GND), A1.13 (GND), A1.18 (GND), A1.23 (GND), A1.28 (GND), A1.38 (GND), J1.1 (GND), J1.2 (GND), J1.15 (GND), J1.16 (GND), J2.6 (GND), J2.9 (GND), J2.14 (GND), J2.20 (GND), J2.25 (GND), J2.30 (GND), J2.34 (GND), J2.39 (GND), RN2.1 (common), RN3.1 (common)
GPIB_ATN: A1.14 (GPIO10), J2.21 (ATN), RN2.7 (R6)
GPIB_DAV: A1.15 (GPIO11), J2.19 (DAV), RN2.6 (R5)
GPIB_DC: A1.31 (GPIO26_ADC0), J2.23 (DC)
GPIB_DIO1: A1.10 (GPIO7), J2.29 (DIO1), RN3.9 (R8)
GPIB_DIO2: A1.9 (GPIO6), J2.31 (DIO2), RN3.8 (R7)
GPIB_DIO3: A1.7 (GPIO5), J2.32 (DIO3), RN3.7 (R6)
GPIB_DIO4: A1.6 (GPIO4), J2.33 (DIO4), RN3.6 (R5)
GPIB_DIO5: A1.5 (GPIO3), J2.35 (DIO5), RN3.5 (R4)
GPIB_DIO6: A1.4 (GPIO2), J2.36 (DIO6), RN3.4 (R3)
GPIB_DIO7: A1.2 (GPIO1), J2.37 (DIO7), RN3.3 (R2)
GPIB_DIO8: A1.1 (GPIO0), J2.38 (DIO8), RN3.2 (R1)
GPIB_EOI: A1.12 (GPIO9), J2.22 (EOI), RN2.8 (R7)
GPIB_IFC: A1.19 (GPIO14), J2.16 (IFC), RN2.3 (R2)
GPIB_NDAC: A1.17 (GPIO13), J2.15 (NDAC), RN2.4 (R3)
GPIB_NRFD: A1.16 (GPIO12), J2.18 (NRFD), RN2.5 (R4)
GPIB_PE: A1.40 (VBUS), J2.2 (5V), J2.4 (5V), J2.40 (PE)
GPIB_REN: A1.20 (GPIO15), J2.13 (REN), RN2.2 (R1)
GPIB_SRQ: A1.11 (GPIO8), J2.24 (SRQ), RN2.9 (R8)
GPIB_TE: A1.32 (GPIO27_ADC1), J2.26 (TE)
SPI_CS: A1.22 (GPIO17), J1.7 (CS), J1.8 (CS)
SPI_MISO: A1.21 (GPIO16), J1.13 (MISO), J1.14 (MISO)
SPI_MOSI: A1.25 (GPIO19), J1.9 (MOSI), J1.10 (MOSI)
SPI_SCK: A1.24 (GPIO18), J1.11 (SCK), J1.12 (SCK)

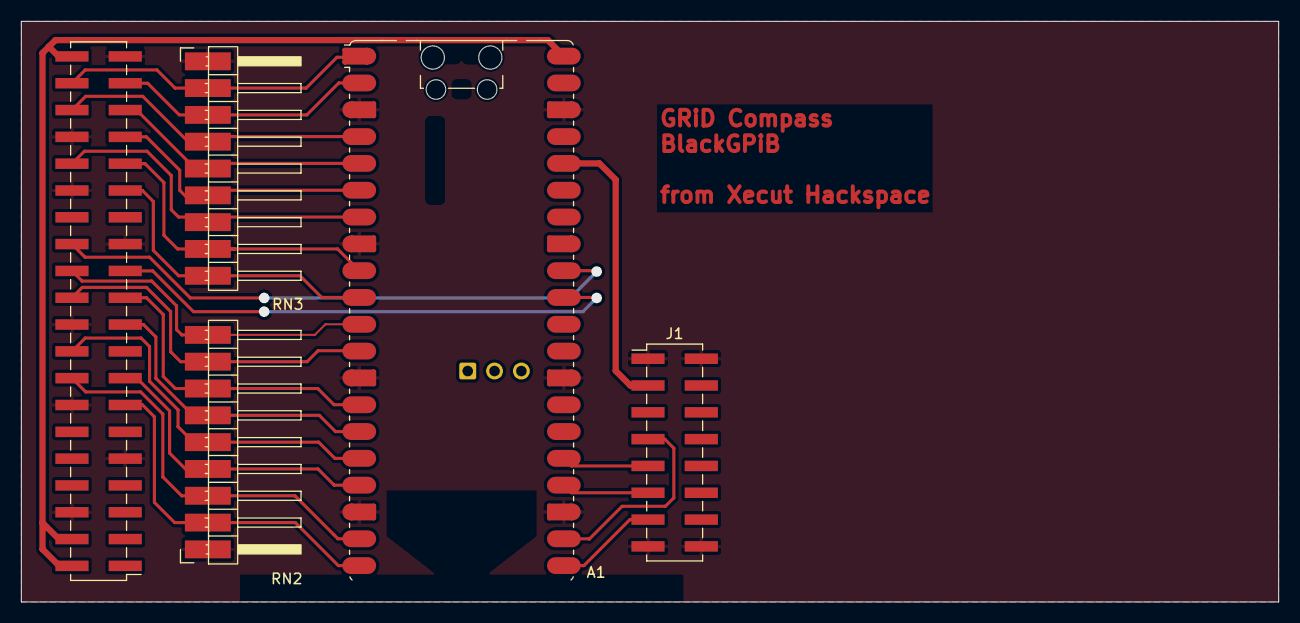
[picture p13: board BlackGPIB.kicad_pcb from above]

Board: 2 copper layers, 119.1 x 55.0 mm, 5 parts (0 on the bottom side), 25 nets.

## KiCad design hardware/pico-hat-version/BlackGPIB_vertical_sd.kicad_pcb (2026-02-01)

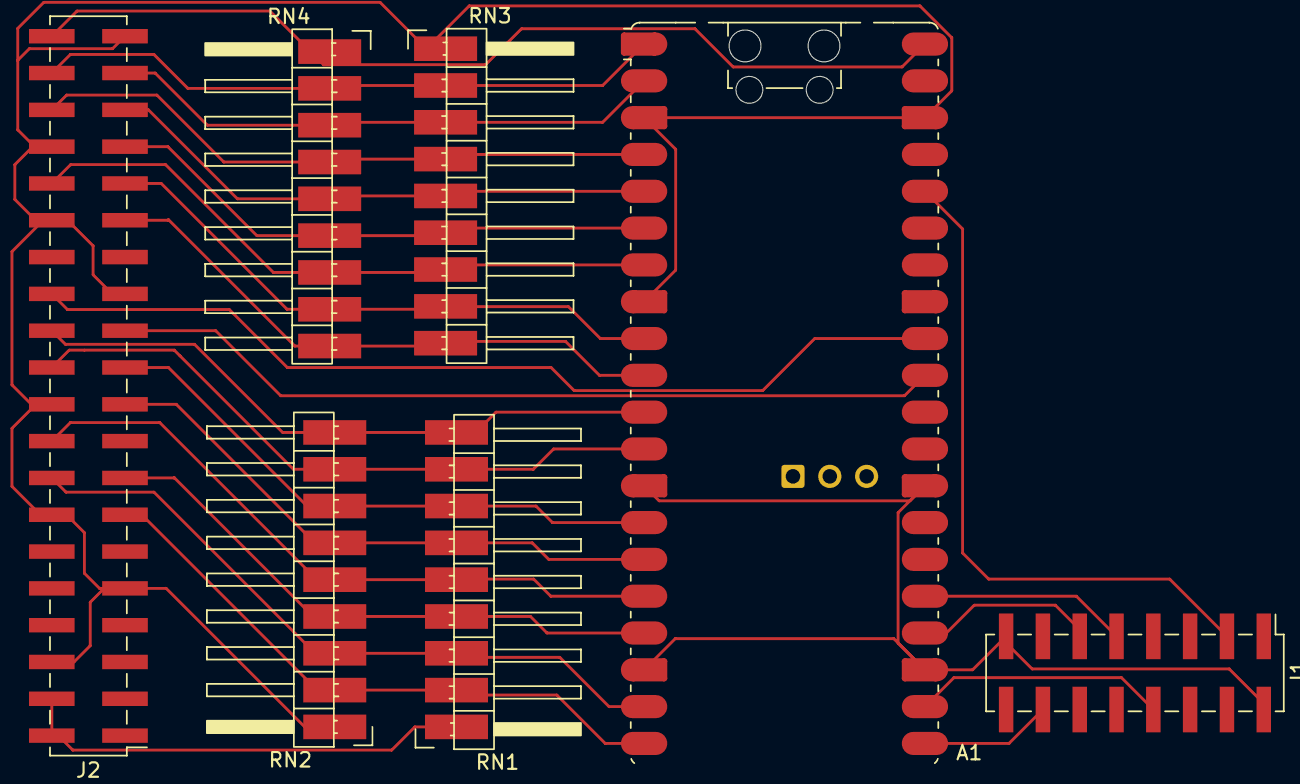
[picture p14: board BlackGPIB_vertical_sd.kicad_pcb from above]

Board: 2 copper layers, 7 parts (0 on the bottom side), 25 nets.

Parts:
A1: RaspberryPi_Pico; RaspberryPi_Pico_W_SMD_HandSolder
J1: SD_Card_Module; PinHeader_2x08_P2.54mm_Vertical_SMD
J2: Raspberry_Pi_Connector; PinHeader_2x20_P2.54mm_Vertical_SMD
RN1, RN4: 3K3; PinHeader_1x09_P2.54mm_Horizontal_Left
RN2, RN3: 6K8; PinHeader_1x09_P2.54mm_Horizontal_Right

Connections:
+3.3V: A1.36 (3V3), J1.3 (3.3V), J1.4 (3.3V)
+5V: A1.40 (VBUS), J2.2 (5V), J2.4 (5V), J2.40 (PE), RN1.1 (common), RN4.1 (common)
GND: A1.3 (GND), A1.8 (GND), A1.13 (GND), A1.18 (GND), A1.23 (GND), A1.28 (GND), A1.38 (GND), J1.1 (GND), J1.2 (GND), J1.15 (GND), J1.16 (GND), J2.6 (GND), J2.9 (GND), J2.14 (GND), J2.20 (GND), J2.25 (GND), J2.30 (GND), J2.34 (GND), J2.39 (GND), RN2.1 (common), RN3.1 (common)
GPIB_ATN: A1.14 (GPIO10), J2.21 (ATN), RN1.7 (R6), RN2.7 (R6)
GPIB_DAV: A1.15 (GPIO11), J2.19 (DAV), RN1.6 (R5), RN2.6 (R5)
GPIB_DC: A1.31 (GPIO26_ADC0), J2.23 (DC)
GPIB_DIO1: A1.10 (GPIO7), J2.29 (DIO1), RN3.9 (R8), RN4.9 (R8)
GPIB_DIO2: A1.9 (GPIO6), J2.31 (DIO2), RN3.8 (R7), RN4.8 (R7)
GPIB_DIO3: A1.7 (GPIO5), J2.32 (DIO3), RN3.7 (R6), RN4.7 (R6)
GPIB_DIO4: A1.6 (GPIO4), J2.33 (DIO4), RN3.6 (R5), RN4.6 (R5)
GPIB_DIO5: A1.5 (GPIO3), J2.35 (DIO5), RN3.5 (R4), RN4.5 (R4)
GPIB_DIO6: A1.4 (GPIO2), J2.36 (DIO6), RN3.4 (R3), RN4.4 (R3)
GPIB_DIO7: A1.2 (GPIO1), J2.37 (DIO7), RN3.3 (R2), RN4.3 (R2)
GPIB_DIO8: A1.1 (GPIO0), J2.38 (DIO8), RN3.2 (R1), RN4.2 (R1)
GPIB_EOI: A1.12 (GPIO9), J2.22 (EOI), RN1.8 (R7), RN2.8 (R7)
GPIB_IFC: A1.19 (GPIO14), J2.16 (IFC), RN1.3 (R2), RN2.3 (R2)
GPIB_NDAC: A1.17 (GPIO13), J2.15 (NDAC), RN1.4 (R3), RN2.4 (R3)
GPIB_NRFD: A1.16 (GPIO12), J2.18 (NRFD), RN1.5 (R4), RN2.5 (R4)
GPIB_REN: A1.20 (GPIO15), J2.13 (REN), RN1.2 (R1), RN2.2 (R1)
GPIB_SRQ: A1.11 (GPIO8), J2.24 (SRQ), RN1.9 (R8), RN2.9 (R8)
GPIB_TE: A1.32 (GPIO27_ADC1), J2.26 (TE)
SPI_CS: A1.22 (GPIO17), J1.7 (CS), J1.8 (CS)
SPI_MISO: A1.21 (GPIO16), J1.13 (MISO), J1.14 (MISO)
SPI_MOSI: A1.25 (GPIO19), J1.9 (MOSI), J1.10 (MOSI)
SPI_SCK: A1.24 (GPIO18), J1.11 (SCK), J1.12 (SCK)

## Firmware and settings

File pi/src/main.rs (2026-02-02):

#![allow(clippy::needless_return, clippy::upper_case_acronyms)]

mod args;
mod controller;
mod disk_protocol;
mod emulator;
mod gpib;
mod gpio;
mod logger;
mod sniffer;
mod system;
mod time_utils;

use std::{fs, io, path::Path, process::ExitCode, time::Instant};

use crate::{
    args::{Args, ControllerCommand, EmulatorArgs, SnifferArgs},
    controller::DeviceController,
    disk_protocol::Status,
    emulator::DeviceEmulator,
    gpio::Gpio,
    logger::LogLevel,
    sniffer::BusSniffer,
    system::{DeviceInfo, GpioInterface, SoC},
};

const VERSION: &str = env!("CARGO_PKG_VERSION");

fn main() -> ExitCode {
    let args = Args::parse();

    setup_logger(&args);

    match blackgpib(args) {
        Ok(()) => {
            return ExitCode::SUCCESS;
        }
        Err(err) => {
            error!("BlackGPIB fatal error: {err}");
            return ExitCode::FAILURE;
        }
    }
}

fn setup_logger(args: &Args) {
    logger::setup(if args.trace {
        LogLevel::Trace
    } else if args.verbose {
        LogLevel::Debug
    } else {
        LogLevel::Info
    });
}

fn blackgpib(args: Args) -> io::Result<()> {
    check_device_compatibility()?;
    let gpio = open_gpio()?;

    configure_scheduler()?;

    match args.command {
        args::Command::Emulator(args) => run_emulator(gpio, args),
        args::Command::Sniffer(args) => run_sniffer(gpio, args),
        args::Command::Controller(cmd) => run_controller(gpio, cmd),
    }
}

fn check_device_compatibility() -> io::Result<()> {
    trace!("Check device compatibility");

    match DeviceInfo::new() {
        Ok(info) => match info.gpio_interface() {
            GpioInterface::Bcm if info.soc() != SoC::Bcm2835 => {
                info!("Detected supported {} ({})", info.model(), info.soc());
                return Ok(());
            }
            _ => {
                error!("Sorry, your {} ({}) does not supported :(", info.model(), info.soc());
                return Err(io::Error::new(io::ErrorKind::Unsupported, "detected unsupported Raspberry Pi"));
            }
        },
        Err(err) if err.kind() == io::ErrorKind::Unsupported => {
            return Err(io::Error::new(io::ErrorKind::Unsupported, "unknown Raspberry Pi model"));
        }
        Err(err) => {
            return Err(err);
        }
    }
}

fn open_gpio() -> io::Result<Gpio> {
    trace!("Open GPIO");

    // SAFETY: Initialized only once; no other GPIO exist.
    unsafe { Gpio::new() }
}

fn configure_scheduler() -> io::Result<()> {
    trace!("Pin blackgpib to core 3 and set priority");

    // SAFETY: CPU affinity mask is configured per the documentation.
    let cpu_mask = unsafe {
        let mut set = std::mem::zeroed();
        libc::CPU_ZERO(&mut set);
        libc::CPU_SET(3, &mut set);
        set
    };

    // SAFETY: This call does not cause UB; on error it returns -1.
    let result = unsafe { libc::sched_setaffinity(0, size_of_val(&cpu_mask), &cpu_mask) };
    if result == -1 {
        return Err(io::Error::last_os_error());
    }

    // SAFETY: This call does not cause UB; on error it returns -1.
    // let result = unsafe { libc::setpriority(libc::PRIO_PROCESS, 0, -19) };
    // if result == -1 {
    //     return Err(io::Error::last_os_error());
    // }

    Ok(())
}

fn run_emulator(gpio: Gpio, args: EmulatorArgs) -> io::Result<()> {
    let mut emulator = DeviceEmulator::new();

    debug!("Configure emulator before start");
    configure_emulator(args, &mut emulator)?;

    info!("Start BlackGPIB v{VERSION} emulator");
    emulator.start(gpio);

    Ok(())
}

fn configure_emulator(args: EmulatorArgs, emulator: &mut DeviceEmulator) -> io::Result<()> {
    emulator.create_proxy(21, 49274)?; // default printer
    emulator.create_proxy(25, 49275)?; // printer hp
    emulator.create_proxy(20, 49276)?; // plotter

    if let Some(ref path) = args.hdd_1_image {
        emulator.create_disk(4, mmap_disk_image(path)?)?;
    }
    if let Some(ref path) = args.floppy_drive_1_image {
        emulator.create_disk(5, mmap_disk_image(path)?)?;
    }
    if let Some(ref path) = args.portable_floppy_image {
        emulator.create_disk(6, mmap_disk_image(path)?)?;
    }
    if let Some(ref path) = args.hdd_2_image {
        emulator.create_disk(12, mmap_disk_image(path)?)?;
    }
    if let Some(ref path) = args.floppy_drive_2_image {
        emulator.create_disk(13, mmap_disk_image(path)?)?;
    }

    Ok(())
}

fn mmap_disk_image(path: &Path) -> io::Result<memmap2::MmapMut> {
    debug!("Open disk image {}", path.display());

    let file = fs::OpenOptions::new()
        .read(true)
        .write(true)
        .create(false)
        .truncate(false)
        .open(path)
        .map_err(|err| map_file_error(err, path, "open"))?;

    file.lock().map_err(|err| map_file_error(err, path, "lock"))?;

    // SAFETY: The file is opened and locked; no other process can access it.
    let mmap = unsafe { memmap2::MmapMut::map_mut(&file) }.map_err(|err| map_file_error(err, path, "mmap"))?;

    // The file is needed for the entire emulator lifetime; it must not be dropped.
    std::mem::forget(file);

    return Ok(mmap);
}

fn run_sniffer(gpio: Gpio, args: SnifferArgs) -> io::Result<()> {
    let file = create_dump_file(&args.output_path, args.size)?;
    let sniffer = BusSniffer::new(file);

    info!("Start BlackGPIB v{VERSION} sniffer");

    sniffer.start(gpio);

    info!("Bus sniffer finished, dump saved to {}", args.output_path.display());

    Ok(())
}

fn create_dump_file(path: &Path, size: usize) -> io::Result<memmap2::MmapMut> {
    let file_exists = fs::exists(path).map_err(|err| map_file_error(err, path, "check"))?;
    if file_exists {
        return Err(io::Error::new(io::ErrorKind::AlreadyExists, format!("file {} already exists", path.display())));
    }

    let file = fs::OpenOptions::new()
        .read(true)
        .write(true)
        .create_new(true)
        .open(path)
        .map_err(|err| map_file_error(err, path, "open"))?;

    file.set_len(size as u64)
        .map_err(|err| map_file_error(err, path, "set length of"))?;

    file.lock().map_err(|err| map_file_error(err, path, "lock"))?;

    // SAFETY: The file is opened and locked; no other process can access it.
    let mmap = unsafe { memmap2::MmapMut::map_mut(&file) }.map_err(|err| map_file_error(err, path, "mmap"))?;

    // The file is needed for the entire sniffer lifetime; it must not be dropped.
    std::mem::forget(file);

    return Ok(mmap);
}

fn run_controller(gpio: Gpio, cmd: ControllerCommand) -> io::Result<()> {
    info!("Start BlackGPIB v{VERSION} controller");

    match cmd {
        ControllerCommand::Status { address } => {
            let mut controller = DeviceController::new_with_reset(gpio, address);
            get_disk_status(&mut controller)?;
        }
        ControllerCommand::Format { address, validate } => {
            let mut controller = DeviceController::new_with_reset(gpio, address);
            get_disk_status(&mut controller)?;

            info!("Format disk...");

            let start = Instant::now();
            controller.format_disk(validate)?;

            info!("Disk successfully formatted in {:?}", start.elapsed());
        }
        ControllerCommand::Write {
            from_path: path,
            to_address: address,
        } => {
            let mut controller = DeviceController::new_with_reset(gpio, address);
            let disk_status = get_disk_status(&mut controller)?;
            let image_size = disk_status.size();

            let file = open_file_for_reading(&path, image_size)?;

            info!("Writing image to disk...");

            let start = Instant::now();
            controller.write_image_to_disk(file)?;

            info!("Image {} successfully written to disk in {:?}", path.display(), start.elapsed());
        }
        ControllerCommand::Read {
            from_address: address,
            to_path: path,
        } => {
            let mut controller = DeviceController::new_with_reset(gpio, address);
            let disk_status = get_disk_status(&mut controller)?;
            let image_size = disk_status.size();

            let file = open_file_for_writing(&path, image_size)?;

            info!("Reading disk to image file {}...", path.display());

            let start = Instant::now();
            controller.read_disk_to_writer(file)?;

            info!("Disk successfully read into file {} in {:?}", path.display(), start.elapsed());
        }
    }

    Ok(())
}

fn get_disk_status(controller: &mut DeviceController) -> io::Result<Status> {
    info!("Read disk info");
    let disk_status = controller.read_status()?;

    info!("Device identified as:");
    info!("  Name: '{}'", disk_status.name());
    info!("  Sector Size: {}", disk_status.sector_size);
    info!("  Logical Sector Size: {}", disk_status.logical_sector_size);
    info!("  Disk Status: {}", disk_status.drive_status);
    info!("  Bitmap Block ID: {:#06x}", disk_status.bitmap_block_id);
    info!("  Superblock ID: {:#06x}", disk_status.superblock_id);
    info!("  Min Dir Pages: {}", disk_status.min_dir_pages);
    info!("  Flush: {}", disk_status.flush);
    info!("  Sector Count: {}", disk_status.sector_count);
    info!("  Bytes Per Sector: {}", disk_status.bytes_per_sector);
    info!("  Sectors Per Track: {}", disk_status.sectors_per_track);
    info!("  Tracks Per Cylinder: {}", disk_status.tracks_per_cylinder);
    info!("  Size (bytes): {}", disk_status.size());

    Ok(disk_status)
}

fn open_file_for_reading(path: &Path, file_size: usize) -> io::Result<fs::File> {
    let file = fs::OpenOptions::new()
        .create(false)
        .read(true)
        .write(false)
        .open(path)
        .map_err(|err| map_file_error(err, path, "open"))?;

    file.lock().map_err(|err| map_file_error(err, path, "lock"))?;

    let file_metadata = file
        .metadata()
        .map_err(|err| map_file_error(err, path, "get metadata of"))?;

    if file_metadata.len() != file_size as u64 {
        return Err(io::Error::new(
            io::ErrorKind::InvalidInput,
            format!("file must be exactly {file_size} bytes long"),
        ));
    }

    Ok(file)
}

fn open_file_for_writing(path: &Path, file_size: usize) -> io::Result<fs::File> {
    let file = fs::OpenOptions::new()
        .create(true)
        .truncate(true)
        .read(false)
        .write(true)
        .open(path)
        .map_err(|err| map_file_error(err, path, "open"))?;

    file.lock().map_err(|err| map_file_error(err, path, "lock"))?;

    file.set_len(file_size as u64)
        .map_err(|err| map_file_error(err, path, "set length of"))?;

    Ok(file)
}

fn map_file_error(err: io::Error, path: &Path, action: &str) -> io::Error {
    io::Error::new(err.kind(), format!("failed to {action} file {}: {}", path.display(), err))
}

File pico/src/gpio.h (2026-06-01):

#pragma once

#include "hardware/gpio.h"

#define PIN_GPIB_DIO1     8
#define PIN_GPIB_DIO2     9
#define PIN_GPIB_DIO3     10
#define PIN_GPIB_DIO4     11
#define PIN_GPIB_DIO5     12
#define PIN_GPIB_DIO6     13
#define PIN_GPIB_DIO7     14
#define PIN_GPIB_DIO8     15
#define PIN_GPIB_REN      0
#define PIN_GPIB_IFC      1
#define PIN_GPIB_NDAC     2
#define PIN_GPIB_NRFD     3
#define PIN_GPIB_DAV      4
#define PIN_GPIB_ATN      6
#define PIN_GPIB_EOI      5
#define PIN_GPIB_SRQ      7
#define PIN_GPIB_PE       28
#define PIN_GPIB_TE       27
#define PIN_GPIB_DC       26

#define PIN_SD_CARD_MISO  16
#define PIN_SD_CARD_MOSI  19
#define PIN_SD_CARD_SCK   18
#define PIN_SD_CARD_CS    17

#define PIN_LED           25

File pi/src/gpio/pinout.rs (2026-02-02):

//! Valid pin list for the BlackGPIB board.

#[derive(Clone, Copy, Debug)]
#[repr(u8)]
pub enum KnownPin {
    /// Transfer Enable/Talk Enable (SN75161 and 162).
    TE = 7,
    /// Direction Control (SN75161 and 162).
    DC = 11,
    /// System Control (SN75162 only).
    SC = 17,
    /// System Control (SN75161 and 162).
    PE = 21,

    /// Data Input/Output, bit 1.
    DIO1 = 5,
    /// Data Input/Output, bit 2.
    DIO2 = 6,
    /// Data Input/Output, bit 3.
    DIO3 = 12,
    /// Data Input/Output, bit 4.
    DIO4 = 13,
    /// Data Input/Output, bit 5.
    DIO5 = 19,
    /// Data Input/Output, bit 6.
    DIO6 = 16,
    /// Data Input/Output, bit 7.
    DIO7 = 26,
    /// Data Input/Output, bit 8.
    DIO8 = 20,

    /// Data Available.
    DAV = 10,
    /// Not Ready For Data.
    NRFD = 24,
    /// Not Data Accepted.
    NDAC = 22,

    /// Attention.
    ATN = 9,
    /// Interface Clear.
    IFC = 23,
    /// Service Request.
    SRQ = 8,
    /// Remote Enable.
    REN = 27,
    /// End Or Identify.
    EOI = 25,
}

impl KnownPin {
    pub const fn all() -> [Self; 20] {
        [
            KnownPin::TE,
            KnownPin::DC,
            KnownPin::SC,
            KnownPin::PE,
            KnownPin::DIO1,
            KnownPin::DIO2,
            KnownPin::DIO3,
            KnownPin::DIO4,
            KnownPin::DIO5,
            KnownPin::DIO6,
            KnownPin::DIO7,
            KnownPin::DIO8,
            KnownPin::DAV,
            KnownPin::NRFD,
            KnownPin::NDAC,
            KnownPin::ATN,
            KnownPin::IFC,
            KnownPin::SRQ,
            KnownPin::REN,
            KnownPin::EOI,
        ]
    }

    pub const fn data() -> [KnownPin; 8] {
        [
            KnownPin::DIO1,
            KnownPin::DIO2,
            KnownPin::DIO3,
            KnownPin::DIO4,
            KnownPin::DIO5,
            KnownPin::DIO6,
            KnownPin::DIO7,
            KnownPin::DIO8,
        ]
    }
}

const _: () = {
    let pins = KnownPin::all();

    let mut i = 0;
    while i < pins.len() {
        assert!((pins[i] as u8) < 32, "all pins must be in range 0..32");
        i += 1;
    }
};

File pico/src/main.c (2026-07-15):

#include "blackgpib.h"
#include "logging.h"
#include "gpio.h"
#include "watchdog.h"
#include "sd_card.h"
#include "adapter.h"

#include "pico/stdlib.h"
#include "pico/multicore.h"
#include "hardware/gpio.h"

#include <stdlib.h>
#include <stdio.h>
#include <inttypes.h>

static void configure_led(void) {
  gpio_init(PIN_LED);
  gpio_set_dir(PIN_LED, GPIO_OUT);
}

static void blink_sos(void) {
#define DOT 80

  while (true) {
    gpio_put(PIN_LED, 0);

    for (int i = 0; i < 3 * 2; i++) {
      gpio_xor_mask(1 << PIN_LED);
      sleep_ms(DOT);
    }

    for (int i = 0; i < 3; i++) {
      gpio_xor_mask(1 << PIN_LED);
      sleep_ms(DOT * 3);
      gpio_xor_mask(1 << PIN_LED);
      sleep_ms(DOT);
    }

    for (int i = 0; i < 3 * 2; i++) {
      gpio_xor_mask(1 << PIN_LED);
      sleep_ms(DOT);
    }

    sleep_ms(1000);
  }

#undef DOT
}

static void setup_sd_card_log(void) {
  char* fs = "FAT";
  switch (sd_card_get_type()) {
    case FS_FAT12: fs = "FAT12"; break;
    case FS_FAT16: fs = "FAT16"; break;
    case FS_FAT32: fs = "FAT32"; break;
    case FS_EXFAT: fs = "EXFAT"; break;
  }

  sd_card_log_init();

  LOG_SD_CARD("BlackGPIB v" PICO_PROGRAM_VERSION_STRING "\n"
              "Board '" PICO_BOARD "'\n"
              "SD Card detected, %s volume size: %" PRIu64 " MB\n"
              "\n",
              fs, sd_card_get_size() / 1024 / 1024);
}

static void build_emulators(disk_emulator_t* emulators[MAX_DEVICES]) {
  const uint8_t DEAFULT_ADDRESSES[5] = {4, 5, 6, 12, 13};
  const uint8_t FDD_ADDRESSES[3] = {5, 6, 13};

  sd_card_image_loaders_list_t list = sd_card_get_image_loaders();

  // fill slots according to the file names.
  for (size_t i = 0; i < list.size; i++) {
    sd_card_image_loader_item_t* item = &list.ptr[i];
    if (item->gpib_address != NO_GPIB_ADDRESS) {
      if (emulators[item->gpib_address] == NULL) {
        emulators[item->gpib_address] = disk_emu_new(item->loader);

        LOG_SD_CARD("Bind image '%s' to address %d\n",
                    item->file_name, (int)item->gpib_address);
      } else {
        LOG_SD_CARD("Failed to bind image '%s' to address %d: address already busy\n",
                    item->file_name, (int)item->gpib_address);
      }
    }
  }

  // fill slots with floppy images.
  for (size_t i = 0; i < list.size; i++) {
    sd_card_image_loader_item_t* item = &list.ptr[i];
    disk_geometry_t geometry = item->loader.vtable->geometry(item->loader.self);

    // skip all files with addresses in file names.
    if (item->gpib_address != NO_GPIB_ADDRESS) {
      continue;
    }

    // all floppy images has 720 sectors (360KiB, DS DD).
    if (geometry.total_sectors != 720) {
      continue;
    }

    uint8_t free_address = NO_GPIB_ADDRESS;

    for (size_t j = 0; j < sizeof(FDD_ADDRESSES); j++) {
      if (emulators[FDD_ADDRESSES[j]] == NULL) {
        free_address = FDD_ADDRESSES[j];
        break;
      }
    }

    if (free_address != NO_GPIB_ADDRESS) {
      emulators[free_address] = disk_emu_new(item->loader);

      LOG_SD_CARD("Bind floppy image '%s' to address %d\n",
                  item->file_name, (int)free_address);
    } else {
      LOG_SD_CARD("Failed to bind floppy image '%s': no free slots, please specify address in file name\n",
                  item->file_name);
    }
  }

  // fill slots with other images.
  for (size_t i = 0; i < list.size; i++) {
    sd_card_image_loader_item_t* item = &list.ptr[i];
    disk_geometry_t geometry = item->loader.vtable->geometry(item->loader.self);

    // skip all files with addresses in file names.
    if (item->gpib_address != NO_GPIB_ADDRESS) {
      continue;
    }

    // skip all floppy images.
    if (geometry.total_sectors == 720) {
      continue;
    }

    uint8_t free_address = NO_GPIB_ADDRESS;

    for (size_t j = 0; j < sizeof(DEAFULT_ADDRESSES); j++) {
      if (emulators[DEAFULT_ADDRESSES[j]] == NULL) {
        free_address = DEAFULT_ADDRESSES[j];
        break;
      }
    }

    if (free_address != NO_GPIB_ADDRESS) {
      emulators[free_address] = disk_emu_new(item->loader);

      LOG_SD_CARD("Bind image '%s' to address %d\n",
                  item->file_name, (int)free_address);
    } else {
      LOG_SD_CARD("Failed to bind image '%s': no free slots, please specify address in file name\n",
                  item->file_name);
    }
  }

  free(list.ptr);
}

int main() {
  stdio_init_all();

  sleep_ms(1500);

  configure_led();

  if (wd_take_adapter_mode()) {
    wd_reset_reboot_count();
    adapter_run();
  } else {
      multicore_launch_core1(adapter_wait_connect);
  }

  if (wd_get_reboot_count() >= 3) {
    LOG_FATAL("boot loop detected!\n");
    blink_sos();
  }

  sd_card_init();
  setup_sd_card_log();

  disk_emulator_t* emulators[MAX_DEVICES] = {0};
  build_emulators(emulators);

  blackgpib_t* blackgpib = blackgpib_new(emulators);

  LOG_SD_CARD("\nInitialization complete!");

  gpio_put(PIN_LED, 1);

  wd_reset_reboot_count();
  blackgpib_run(blackgpib);

  return 0;
}

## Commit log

2025-10-28 Kirill Leyfer's unfinished emulator
    [Session 0.csv, Session 1.csv, Session 2.csv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]
2025-10-29 try to adapt sources to the new board
2025-10-31 newver: fix byte read
    [gpio.rs, main.rs]
2025-10-31 change project structure
    [Session 0.csv, Session 1.csv, Session 2.csv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]
2025-11-01 speedup data reading, fix last byte loss
    Compass reset data lines without waiting for the disk, without waiting for us to raise the NDAC. This is a violation of the standard, but there's nothing we can do about it. We just need to read the data as quickly as possible before it's lost.
    It's a dangerous situation, but there's no solution yet.
    [main.rs]
2025-11-01 unwrap all gpio errors, remove all ???????
    [gpio.rs, main.rs]
2025-11-03 use log crate and hand made logger instead of println's
2025-11-10 revert "custom rt logger from Cursor"
    this reverts commit 42d3d88642f886ec6d2344506e6bbc0f9c20d821.
    [main.rs, mod.rs]
2025-11-10 prototype of device manager
2025-11-10 fix serial poll tracking, first boot with new disk emu
    [main.rs, mod.rs, talker.rs]
2025-11-11 create common device that proxy listened data to unix socket
2025-11-12 broadcast to udp port instead of unix socket
2025-11-12 add JDat's board
    [untitled.GBL, untitled.GBO, untitled.GBP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]
2025-11-12 add flag to enable trace or verbose logs
2025-11-12 clear buffer after request processing, fix crash on Write
    [mod.rs]
2025-11-12 temporary hack for issue #6, fix MS-DOS 2.11 boot
    [mod.rs]
2025-11-12 hack Initialize request for issue #2, fix MS-DOS 2.00A boot
    [mod.rs]
2025-12-01 pin blackgpib to core 3, without available parallelism math
2025-12-01 enable pullups, fix bus hang when second device connected
    [listener.rs, talker.rs]
2025-12-07 implement sniffer
    I'm too tired of the logic analyzer
2025-12-07 fix Format, initialize only first 8 bytes with 0xFF
    [mod.rs]
2025-12-07 add response structure for disk emulator and fix response for Write req
    [mod.rs]
2025-12-09 rename folder devices to emulator
2025-12-09 connect only requested disks
    Previously, to debug the emulator with a real device on bus, it was necessary to comment some addresses in KnownDevices.
    Also emulator incorrectly handled "uninserted" image, which cause issues with laptop.
    There is no measurable difference in speed between the old approach and the new one, but this makes further improvements much easier.
    [main.rs, mod.rs]
2025-12-15 rewrite listener gpib handshake from scratch
    After reverse engineering the 2101 floppy drive firmware, it turned out
    that the floppy drive behaves differently on the bus.
    I decided not to follow the standard, but to transfer the logic from the
    original peripheral.
    This doesn’t fix anything explicitly, but now I’m confident in the
    correctness of the handshakes and command handling.
    [listener.rs, mod.rs]
2025-12-16 do not reset ndac if dav is high on command handshake
    [listener.rs]
2025-12-16 fix serial poll state machine
    [mod.rs]
2025-12-21 hack nanosleep with busy_wait
    fixes awful 2ms lag on gpio configuration
    [main.rs]
2025-12-22 fork rppal, remove all thread safe code and std::thread::sleep
2025-12-22 rewrite busy_wait using cntfrq и cntvct
2025-12-24 rework talker to dc=low, te=high and remove bias setup
    [listener.rs, mem.rs, talker.rs]
2025-12-25 rework error handling in main
    [main.rs]
2025-12-25 fix logs, add comments
    [listener.rs, mem.rs, mod.rs]
2025-12-28 implement reset and format in DeviceController
    [main.rs, mod.rs]
2025-12-28 fix code after bad rebase
    [main.rs, mod.rs, talker.rs]
2025-12-28 rework logs for controller mode, improve error handling
    [main.rs, mod.rs]
2025-12-28 fix talker and listener for controller mode (emulator still works)
    [listener.rs, talker.rs]
2025-12-28 wait 15 seconds after reset like real laptop
    [mod.rs]
2025-12-28 add "controller status" command to get info about gpib device
2025-12-28 remove asserts in controller, replace with proper error handling
    [mod.rs]
2025-12-28 rewrite logs and error in controller format command
    [mod.rs]
2025-12-28 prevent blackgpib from running on Raspberry Pi 1
    because blackgpib requires one dedicated core
    [main.rs]
2026-02-01 add pico hatted board schematic
    [BlackGPIB.kicad_pcb, BlackGPIB.kicad_sch]
2026-02-01 add pico hello world
2026-02-01 fix pico hatted version: swap dc te and fix dc te on schematic
    [BlackGPIB.kicad_sch]
2026-02-02 move board from @JDat to separate folder
    [untitled.GBL, untitled.GBO, untitled.GBP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]
2026-02-02 move linux version source code to subdirectory "pi"
    [Session 0.csv, Session 1.csv, Session 2.csv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]
2026-02-03 pi pico demo firmware (just to test hardware)
2026-02-07 fix voltage divider for pico hat hardware
    [BlackGPIB.kicad_pcb, BlackGPIB.kicad_sch]
2026-02-07 fix gpib address in pico firmware
    [blackgpib.c]
2026-02-07 continue debugging pico version
2026-02-08 pico: fix handshakes in listening function
    [blackgpib.c]
2026-02-08 pico: fix logs, continue debugging
    [blackgpib.c]
2026-02-08 pico: invert bits when sending byte
    [blackgpib.c]
2026-02-08 pico: fix request handling
    [blackgpib.c]
2026-02-08 pico: split request handling to multiple functions
2026-02-08 pico: fix srq handling, first boot without any timeout issues
    [blackgpib.c]
2026-02-08 pico: read/write data from/to sd card
2026-02-09 pico: split firmware into multiple files
2026-02-11 pico: optimize hatted version for SLA printer, remove optional components
    [BlackGPIB.kicad_pcb, BlackGPIB.kicad_sch]
2026-02-14 pico: add ground polygon and improve traces in hatted version
    [BlackGPIB.kicad_pcb]
2026-02-15 pico: move DC TE traces in hatted version to make handicraft easier
    [BlackGPIB.kicad_pcb]
2026-02-15 pico: fix several warnings and UBs
    [blackgpib.c, gpib.c]
2026-02-18 pi: swap srq and atn on the gpib hat and fix import issues
    [untitled.kicad_pcb, untitled.kicad_sch]
2026-02-23 pico: add rev 1 board
    [BlackGPIB Pico.kicad_pcb, BlackGPIB Pico.kicad_sch, Centronics 24.step]
2026-02-23 pico: add 47uF tantalum capacitor near sd card slot to rev 1 board
    [BlackGPIB Pico.kicad_pcb, BlackGPIB Pico.kicad_sch]
2026-02-23 pico: fix disconnected pads and zones on rev 1 board
    [BlackGPIB Pico.kicad_pcb]
2026-05-09 pico: fix pinout for rev 1 board, configure PE
    [gpib.c, gpio.h]
2026-06-01 pico: move all file operations to loaders, handle sd card errors
    [blackgpib.c, gpio.h]
2026-06-01 pico: blink on gpib activity
2026-06-01 pico: replace all printfs with LOG_* macro, disable debug logs
    [blackgpib.c, gpib.c]
2026-06-01 pico: support multiple devices, but still use demo images
2026-06-02 pico: guess geometry in img loader
2026-06-02 pico: select disk parameters based on image geometry
2026-06-02 pico: support image formatting
2026-06-02 pico: code format, fix compilation
2026-06-02 pico: fix handshake for MLA gpib command
    [blackgpib.c]
2026-06-04 pico: load list of images from sd card, move sd card ops to sd_card.c
2026-06-04 pico: refactor logging, save some logs to sd card
2026-06-04 pico: reboot loop protection to save sd card
    [main.c, sd_card.c]
2026-06-04 pico: do not remount fs in sd_card_get_image_loaders, fix boot
    [sd_card.c]
2026-06-04 pico: add more logs for errors
    [main.c, sd_card.c]
2026-06-04 pico: sync files after write
2026-06-04 pico: add manual to README.md
2026-07-05 pico: fix number of ceramic capacitors in README.md
2026-07-05 pico: fix value of resistor pack in README.md
2026-07-15 pico: add stub adapter mode
2026-07-15 pico: add stubs for some adapter commands
2026-07-15 pico: add helper to parse numbers and print hex to adapter
2026-07-15 pico: slop adapter implementation
    [adapter.c]
2026-07-15 Revert "pico: slop adapter implementation"
    This reverts commit 2e5dab2634083491b622efdf8e32ee11ba9aabaa.
    [adapter.c]
